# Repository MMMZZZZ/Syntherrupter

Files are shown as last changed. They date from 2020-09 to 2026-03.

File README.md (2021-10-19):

# Syntherrupter

Powerful MIDI interrupter with touchscreen for up to 6 tesla coils and 16 voices per coil. 

By Max Zuidberg. Credits [below](#credits).

## Index 

* [Features](#features)
* [Documentation and Getting Started](#documentation-and-getting-started)
* [Pictures](#pictures)
* [Demo Videos](#demo-videos)
* [PC MIDI Setup](#pc-midi-setup)
* [Credits](#credits)

## Features

* A unique and truly awesome name: Syntherrupter. ;D 
* **Easy to build**. Except for the optical transmitters the other parts are "ready to use" modules that can be connected without soldering or custom PCBs.
* **Over 10 voice polyphony** including effects like pitch bend, modulation and different "instruments". Yes, you can - within limits - change how your coil sounds.
* Control up to **6 independant tesla coils** with only one interrupter. And yes, each output can play different notes. Simply select which output should listen to which MIDI channel.
* Set and change hard limits for each coil. They will be stored even when powered off and assure that you don't fry your tesla coil no matter how crazy the MIDI file is.
* Advanced stereo features. Notes and MIDI channels can seamlessly change between multiple coils, creating **fascinating visual effects**.
* **Lightsabers**! An ESP8266, an IMU and a battery form a lightsaber that connects to Syntherrupter and allows "lightsaber-effects" to be played on your tesla coils! (credits: Netzpfuscher)
* Different users with different limits. This is useful if you want to rent the coil to someone else who does not know the coils (thermal?) limits as well as you do.
* **[Controllable via MIDI files](https://github.com/MMMZZZZ/Syfoh#readme)**. Any configuration can be embedded into your MIDI file. Just hit play and everything else happens automagically.
* Sounds boring, but for me it belongs to an interrupter as well: **Normal interrupter mode** where you can control the ontime, BPS and duty.
* **[Documentation/Wiki](/Documentation/Wiki#readme)**. This is not a joke; the wiki contains almost as much work as the software itself. It's not perfect but it covers pretty much everything from simple guides to technical documnetation.

## Documentation and Getting Started

Pretty much everything can be found in the [Wiki](/Documentation/Wiki#readme). For newcomers, there's a [Getting Started Guide](/Documentation/Wiki/Getting%20Started.md#readme). 

## Pictures

SimonNwardUKs version for 4 coils:
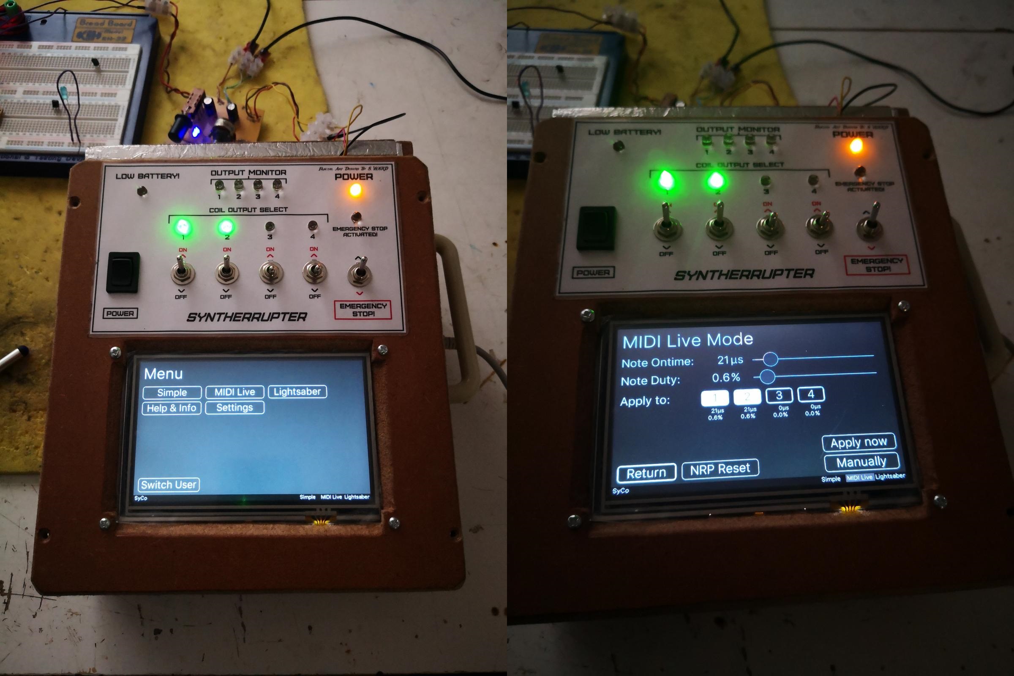
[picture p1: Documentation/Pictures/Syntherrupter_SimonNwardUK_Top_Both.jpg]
Syntherrupter Max Back


Internals of my single output version (with excessive optical receiver):
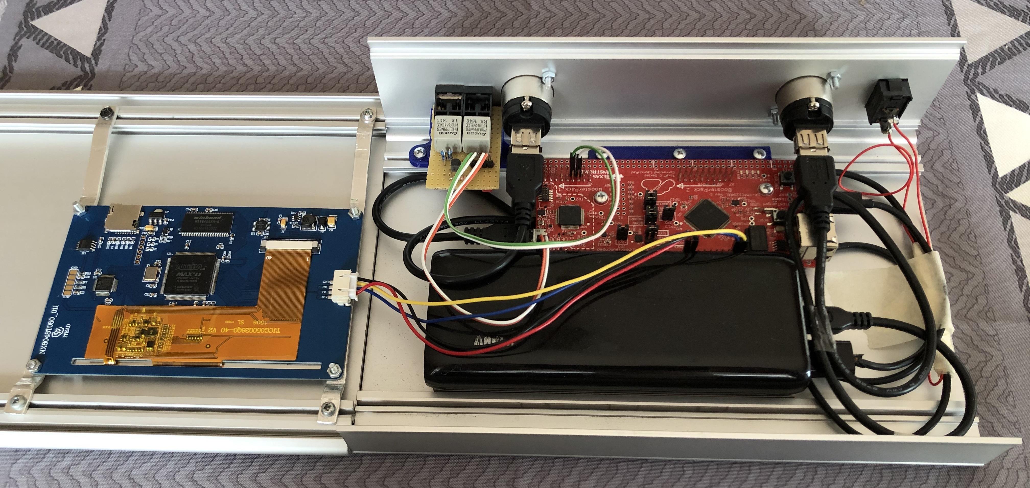
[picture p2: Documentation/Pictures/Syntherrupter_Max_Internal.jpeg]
Syntherrupter Max Inside


## Demo Videos

The following two videos demonstrate Syntherrupters capabilities but there are no arcs because I haven't had any opportunity to run my tesla coil. 

* [Queen - I Want It All](http://www.youtube.com/watch?v=H2ykCsD_b5g). A MIDI with ~6 voices, pitch bending, sometimes very fast notes, and other effects.

* [ACDC - Thunderstruck](http://www.youtube.com/watch?v=Tyts9u0le6A). This is a 6 channel demo of Syntherrupters stereo features with Thunderstruck. The only modification made to the MIDI file, were the commands that set up Syntherrupters stereo mode (documented [here](/Documentation/Wiki/Custom%20MIDI%20Commands.md)). The mapping of the notes to the coils (represented by LEDs) in done automatically.

    *"I must say that the Omni-mode is what I have dreamt about for years, I am really looking forward to use that feature (and not so much that I now have to build 6 identical coils)"* ([from Mads Barnkob](https://highvoltageforum.net/index.php?topic=1020.msg8430#msg8430))

* [ABBA - Gimme! Gimme! Gimme!](https://www.youtube.com/watch?v=6n-RvNdsbxE). Perfect demo of the [staccato envelope](/Documentation/Wiki/Envelopes.md#readme). Note how the low notes are not "on, off" but more like a quick fade in and fade out with slight reverb. That's the envelope. Compare it with the videos below, which do not use this feature

Then there are a few videos from other people that build their own Syntherrupter:
* [Video (performed by Georgios)](https://www.youtube.com/watch?v=1vgiw4VHPKQ). Fast MIDI with 2 tesla coils and up to 4 notes per coil
* [O-Zone - Dragostea Din Tei (performed by futurist)](https://www.youtube.com/watch?v=86U6sI6FZ6c). 1 Coil, two notes, nonetheless a good MIDI.
* [Fonsi - Despacito and much more (performed by futurist)](https://www.youtube.com/playlist?list=PLlkH_ZpBGiexB1ahBjtajvHqJAfMIxrB1). Playlist with a lot of popular songs. Usually only 2 notes at most, played by 2 coils. 

## PC MIDI Setup

To open and play MIDI files I use the free software [SynthFont 1](http://www.synthfont.com/). You can select a different output for each track which we can use to send some tracks to the interrupter. You might want to change the instrument of these tracks to use Syntherrupters [envelopes](/Documentation/Wiki/Envelopes.md#readme). For good sound quality download the [SGMv2.01-Sal-Guitar-Bass-v1.3](https://sites.google.com/site/soundfonts4u) soundfont).

While SynthFont allows you to send MIDI data directly to a serial port and thus to Syntherrupter, I do recommend another solution. In my experience it is easier to use, more reliable and works with any MIDI software you like. All you need are two little tools that are very easy to use: [Hairless MIDI<->Serial](https://projectgus.github.io/hairless-midiserial/) and [loopMIDI](https://www.tobias-erichsen.de/software/loopmidi.html). When you start loopMIDI it creates a virtual MIDI device that you can select in any MIDI software as output (or input btw). And hairless MIDI<->Serial makes the bridge between this virtual MIDI device and the serial COM port.
This sounds complicated but since both programs remember all settings, you only have to start them - no other click needed. The setup has proven its reliability and usability many times and for many hours. 

## Credits

[Netzpfuscher and his awesome UD3](https://highvoltageforum.net/index.php?topic=188.0). Thank you for the initial help with polyphony and the awesome lightsaber idea.

[TMaxElectronics](https://tmax-electronics.de/easteregg/). Many great discussions about MIDI, Interrupters, C/C++ worst practices, and much more. And for developing a competing interrupter - keeps the development going. 

[highvoltageforum](https://highvoltageforum.net). Without those people sharing their ideas and knowledge, Syntherrupter would never be where it is now.

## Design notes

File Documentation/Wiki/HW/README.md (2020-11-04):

# Hardware Reference

[Back to the wiki main page](/Documentation/Wiki/README.md#readme)

This page and its subpages document every aspect of Syntherrupters hardware.

## Content

* [Optical Outputs](Optical%20Outputs.md#readme)
* [MIDI Input Jack](MIDI%20Input.md#readme)
* [Lightsaber Receiver](Lightsaber%20Receiver.md#readme)

All the schematics and pinouts you see in these pages come from the *[Wiring and Schematics](/Documentation/Wiring%20and%20Schematics)* folder. It contains not only the pictures but also the source files (f.ex. Fritzing files).

All of the Datasheets and manuals can be found in the  *[Datasheets](/Documentation/Datasheets)* folder.

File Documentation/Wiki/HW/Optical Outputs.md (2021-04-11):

# Optical Outputs

[Back to the hardware documentation overview](README.md#readme)

The connection between interrupter and tesla coil driver is usually made with fibre optics. This page explains how to add optic transmitters to Syntherrupter. 

Syntherrupter can generate up to 6 independant interrupter signals (for up to 6 independent tesla coils). You're completely free in the choice of how many outputs you want to have on your Syntherrupter; 1, 2, 3, 4, 5 or 6 are possible. In any case you'll need one transmitter per output. 

## Output Pins and Limits

The 6 output signals are available on the following Tiva pins:

* PD0: Output 1
* PD2: Output 2
* PM0: Output 3
* PM2: Output 4
* PM4: Output 5
* PM6: Output 6

All output pins are 3.3V active high and capable of 12mA max. Depending on your transmitter this is not enough to drive its LED. Please check the datasheet for the recommended current. In case your transmitter needs more current (the HFBR-14E4Z f.ex. needs 60mA) you'll need some additional circuitry. Nothing complicated, a standard NPN transistors and 2 resistors do the job. As always, details in the wiring and schematic folder linked at the top.

## Schematic

The following Schematic of a "complete" Syntherrupter shows how to connect the NPN transistors and what resistor values are needed. **Remember** to adjust the LED resistor for your current! The resistor value can easily be calculated using the following formula: `R_LED = (V_CC - V_CE - V_f) / I_f = (4.4 - V_f) / I_f`

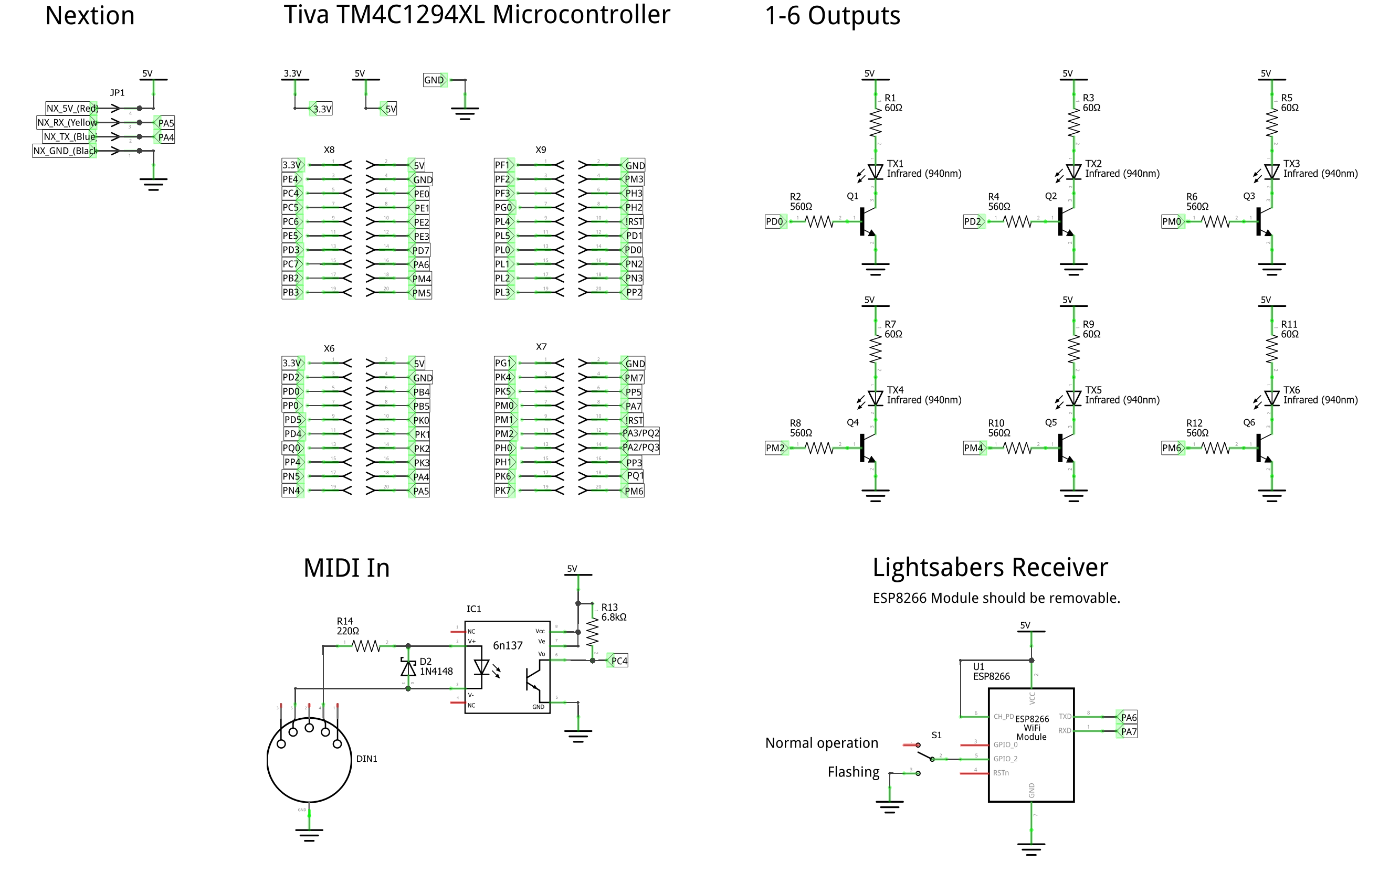
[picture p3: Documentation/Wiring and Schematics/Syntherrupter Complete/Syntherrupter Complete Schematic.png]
Complete Schematic


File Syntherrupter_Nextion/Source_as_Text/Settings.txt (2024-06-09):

Page Settings
    Attributes
        ID               : 0
        Scope            : local
        Send Component ID: disabled
        Locked           : no
    
    Events
        Preinitialize Event
            // Prevent page refreshs until postinit
            ref_stop
            //
            // Load colors
            click fLoadColors,1
            click fLoadModes,1
            //
            // Display username
            if(User_Settings.userNum.val==0)
            {
                tUser.txt=" "+User_Settings.u0Name.txt
            }else if(User_Settings.userNum.val==1)
            {
                tUser.txt=" "+User_Settings.u1Name.txt
            }else if(User_Settings.userNum.val==2)
            {
                tUser.txt=" "+User_Settings.u2Name.txt
            }
            //
            vis fLoadModes,0
            vis fLoadColors,0
            //
            // Properly hide the help stuff.
            vis hHelp,0
            vis tHelp,0
            //
            tSave.bco=Settings.backSelectCol2.val
            vis tSave,Settings.unsaved.val
            // Not all users have the same rights
            if(User_Settings.userNum.val!=2)
            {
                vis bCoilSettings,0
                vis bNXTUpdate,0
                vis bESPUpdate,0
                vis bReset,0
            }
            //
            // Enable page refreshs again
            ref_star
        
        Postinitialize Event
            // Accept data on this page
            // Send a Syntherrupter Sysex command
            // Package format:
            // F0 00 DMID DMID VERSION DEVICE PN_LSB PN_MSB TG_LSB TG_MSB VAL_LSB VAL VAL VAL VAL_MSB F7
            // DMID DMID = 26 05
            // VERSION = 01
            // DEVICE = 7f (wildcard)
            // PN, TG, VAL: see syntherrupter sysex documentation
            //
            // SYSEX_START DMID VERSION DEVICE
            printh f0 00 26 05 01 7f
            // PN_LSB PN_MSB
            printh 26 02 // GUI Update Mode
            // TG_LSB TG_MSB
            printh 00 00 // Reserved
            // VAL (4 bytes to be packed into 5 groups of 7 bit)
            // 2: Keep UI updated
            printh 02 00 00 00 00
            // SYSEX_END
            printh f7
        
        Touch Press Event
            if(Other_Settings.backOff.val!=0)
            {
                // Default "stop" action.
                // Set ontime and duty to 0 for all modes. See fSysex for details
                // Disable all modes as well.
                printh f0 00 26 05 01 7f 20 00 00 7f 00 00 00 00 00 f7
                printh f0 00 26 05 01 7f 21 00 00 7f 00 00 00 00 00 f7
                printh f0 00 26 05 01 7f 22 00 00 7f 00 00 00 00 00 f7
                // Set all ontime and duty settings of all pages to 0.
                // First come the global variables then the local variables.
                Simple.ontime.val=0
                Simple.duty.val=0
                Simple.set1.val=Simple.set1.val&0x0000ffff
                Simple.set2.val=Simple.set2.val&0x0000ffff
                Simple.set3.val=Simple.set3.val&0x0000ffff
                Simple.set4.val=Simple.set4.val&0x0000ffff
                Simple.set5.val=Simple.set5.val&0x0000ffff
                Simple.set6.val=Simple.set6.val&0x0000ffff
                MIDI_Live.ontime.val=0
                MIDI_Live.duty.val=0
                MIDI_Live.set1.val=0
                MIDI_Live.set2.val=0
                MIDI_Live.set3.val=0
                MIDI_Live.set4.val=0
                MIDI_Live.set5.val=0
                MIDI_Live.set6.val=0
                Lightsaber.ontime.val=0
                Lightsaber.ontimes12.val=0
                Lightsaber.ontimes34.val=0
                Lightsaber.ontimes56.val=0
            }
        
        Page Exit Event
            // Leaving this page, the UI might not accept data anymore (any page that still accepts it,
            // will enable it again).
            // Send a Syntherrupter Sysex command
            // Package format:
            // F0 00 DMID DMID VERSION DEVICE PN_LSB PN_MSB TG_LSB TG_MSB VAL_LSB VAL VAL VAL VAL_MSB F7
            // DMID DMID = 26 05
            // VERSION = 01
            // DEVICE = 7f (wildcard)
            // PN, TG, VAL: see syntherrupter sysex documentation
            //
            // SYSEX_START DMID VERSION DEVICE
            printh f0 00 26 05 01 7f
            // PN_LSB PN_MSB
            printh 26 02 // GUI Update Mode
            // TG_LSB TG_MSB
            printh 00 00 // Reserved
            // VAL (4 bytes to be packed into 5 groups of 7 bit)
            // 0: No UI updates
            printh 00 00 00 00 00
            // SYSEX_END
            printh f7
        
Variable (int32) currentHelp
    Attributes
        ID   : 1
        Scope: local
        Value: 4294967295
    
Variable (int32) backCol
    Attributes
        ID   : 2
        Scope: global
        Value: 8484
    
Variable (int32) backCol2
    Attributes
        ID   : 3
        Scope: global
        Value: 2145
    
Variable (int32) frontCol
    Attributes
        ID   : 4
        Scope: global
        Value: 40476
    
Variable (int32) frontCol2
    Attributes
        ID   : 5
        Scope: global
        Value: 40476
    
Variable (int32) backSelectCol2
    Attributes
        ID   : 6
        Scope: global
        Value: 16904
    
Variable (int32) backCol2Deflt
    Attributes
        ID   : 7
        Scope: global
        Value: 4589
    
Variable (int32) colorMode
    Attributes
        ID   : 8
        Scope: global
        Value: 1
    
Variable (int32) picCount
    Attributes
        ID   : 9
        Scope: global
        Value: 43
    
Variable (int32) activeModes
    Attributes
        ID   : 20
        Scope: global
        Value: 0
    
Variable (int32) applyingMode
    Attributes
        ID   : 28
        Scope: global
        Value: 1
    
Variable (int32) firstHelp
    Attributes
        ID   : 31
        Scope: global
        Value: 1
    
Variable (int32) unsaved
    Attributes
        ID   : 32
        Scope: global
        Value: 0
    
Variable (int32) CM0backCol
    Attributes
        ID   : 35
        Scope: global
        Value: 65535
    
Variable (int32) CM0backCol2
    Attributes
        ID   : 36
        Scope: global
        Value: 4589
    
Variable (int32) CM0frontCol
    Attributes
        ID   : 37
        Scope: global
        Value: 6900
    
Variable (int32) CM0frontCol2
    Attributes
        ID   : 38
        Scope: global
        Value: 65535
    
Variable (int32) CM0backSelCol2
    Attributes
        ID   : 39
        Scope: global
        Value: 6900
    
Variable (int32) CM1backCol
    Attributes
        ID   : 40
        Scope: global
        Value: 8484
    
Variable (int32) CM1backCol2
    Attributes
        ID   : 41
        Scope: global
        Value: 2145
    
Variable (int32) CM1frontCol
    Attributes
        ID   : 42
        Scope: global
        Value: 40476
    
Variable (int32) CM1frontCol2
    Attributes
        ID   : 43
        Scope: global
        Value: 40476
    
Variable (int32) CM1backSelCol2
    Attributes
        ID   : 44
        Scope: global
        Value: 16904
    
Text tUser
    Attributes
        ID                 : 10
        Scope              : local
        Send Component ID  : disabled
        Associated Keyboard: none
        Text               :  Guest
        Max. Text Size     : 32
    
    Events
        Touch Press Event
            // Make this object "transparent" for clicks and click background.
            click 0,1
        
Text tMSI
    Attributes
        ID                 : 11
        Scope              : local
        Send Component ID  : disabled
        Associated Keyboard: none
        Text               : Simple
        Max. Text Size     : 16
    
    Events
        Touch Press Event
            // Make this object "transparent" for clicks and click background.
            click 0,1
        
Text tMML
    Attributes
        ID                 : 12
        Scope              : local
        Send Component ID  : disabled
        Associated Keyboard: none
        Text               : MIDI Live
        Max. Text Size     : 16
    
    Events
        Touch Press Event
            // Make this object "transparent" for clicks and click background.
            click 0,1
        
Text tMLS
    Attributes
        ID                 : 13
        Scope              : local
        Send Component ID  : disabled
        Associated Keyboard: none
        Text               : Lightsaber
        Max. Text Size     : 16
    
    Events
        Touch Press Event
            // Make this object "transparent" for clicks and click background.
            click 0,1
        
Text tSave
    Attributes
        ID                 : 14
        Scope              : local
        Send Component ID  : disabled
        Associated Keyboard: none
        Text               : Unsaved Settings!
        Max. Text Size     : 40
    
    Events
        Touch Press Event
            // Make this object "transparent" for clicks and click background.
            click 0,1
        
Text tHelp
    Attributes
        ID                 : 15
        Scope              : local
        Send Component ID  : disabled
        Associated Keyboard: none
        Text               : 
        Max. Text Size     : 650
    
    Events
        Touch Press Event
            // This object is only visible in help mode. No need to be "transparent" to clicks in normal operation.
            click bReturn,0
        
Text tTitle
    Attributes
        ID                 : 17
        Scope              : local
        Send Component ID  : disabled
        Associated Keyboard: none
        Text               : Settings
        Max. Text Size     : 22
    
Button bDiscard
    Attributes
        ID               : 16
        Scope            : local
        Send Component ID: disabled
        State            : unpressed
        Text             : Discard
        Max. Text Size   : 20
    
    Events
        Touch Release Event
            // Force EEPROM Reload
            // Send a Syntherrupter Sysex command
            // Package format:
            // F0 00 DMID DMID VERSION DEVICE PN_LSB PN_MSB TG_LSB TG_MSB VAL_LSB VAL VAL VAL VAL_MSB F7
            // DMID DMID = 26 05
            // VERSION = 01
            // DEVICE = 7f (wildcard)
            // PN, TG, VAL: see syntherrupter sysex documentation
            //
            // EEPROM Reload
            // SYSEX_START DMID VERSION DEVICE
            printh f0 00 26 05 01 7f
            // PN_LSB PN_MSB
            printh 00 02 // EEPROM Update
            // TG_LSB TG_MSB
            printh 00 00 // Reserved
            // VAL (4 bytes to be packed into 5 groups of 7 bit)
            // Update Mode. 1: Reload all settings from EEPROM
            printh 03 00 00 00 00
            // SYSEX_END
            printh f7
            //
            unsaved.val=0
            vis tSave,0
        
Button bReturn
    Attributes
        ID               : 18
        Scope            : local
        Send Component ID: disabled
        State            : unpressed
        Text             : â†
        Max. Text Size   : 3
    
    Events
        Touch Release Event
            page Menu
        
Button bCoilSettings
    Attributes
        ID               : 21
        Scope            : local
        Send Component ID: disabled
        State            : unpressed
        Text             : Coil Limits
        Max. Text Size   : 20
    
    Events
        Touch Release Event
            TC_Settings.origin.val=dp
            page TC_Settings
        
Button bSave
    Attributes
        ID               : 22
        Scope            : local
        Send Component ID: disabled
        State            : unpressed
        Text             : Save
        Max. Text Size   : 10
    
    Events
        Touch Release Event
            // Force EEPROM update
            // Send a Syntherrupter Sysex command
            // Package format:
            // F0 00 DMID DMID VERSION DEVICE PN_LSB PN_MSB TG_LSB TG_MSB VAL_LSB VAL VAL VAL VAL_MSB F7
            // DMID DMID = 26 05
            // VERSION = 01
            // DEVICE = 7f (wildcard)
            // PN, TG, VAL: see syntherrupter sysex documentation
            //
            // EEPROM Update
            // SYSEX_START DMID VERSION DEVICE
            printh f0 00 26 05 01 7f
            // PN_LSB PN_MSB
            printh 00 02 // EEPROM Update
            // TG_LSB TG_MSB
            printh 00 00 // Reserved
            // VAL (4 bytes to be packed into 5 groups of 7 bit)
            // Update Mode. 1: Forced update.
            printh 01 00 00 00 00
            // SYSEX_END
            printh f7
            //
            unsaved.val=0
            vis tSave,0
        
Button bNXTUpdate
    Attributes
        ID               : 23
        Scope            : local
        Send Component ID: disabled
        State            : unpressed
        Text             : Nextion<->USB
        Max. Text Size   : 20
    
    Events
        Touch Release Event
            page USB_NXT_Pass
        
Button bGeneral
    Attributes
        ID               : 24
        Scope            : local
        Send Component ID: disabled
        State            : unpressed
        Text             : General
        Max. Text Size   : 20
    
    Events
        Touch Release Event
            page Other_Settings
        
Button bUsers
    Attributes
        ID               : 25
        Scope            : local
        Send Component ID: disabled
        State            : unpressed
        Text             : Users
        Max. Text Size   : 20
    
    Events
        Touch Release Event
            User_Settings.origin.val=dp
            page User_Settings
        
Button bEnvelope
    Attributes
        ID               : 26
        Scope            : local
        Send Component ID: disabled
        State            : unpressed
        Text             : Envelopes
        Max. Text Size   : 20
    
    Events
        Touch Release Event
            Env_Settings.origin.val=dp
            page Env_Settings
        
Button bESPUpdate
    Attributes
        ID               : 27
        Scope            : local
        Send Component ID: disabled
        State            : unpressed
        Text             : ESP<->USB
        Max. Text Size   : 20
    
    Events
        Touch Release Event
            page USB_ESP_Pass
        
Button bReset
    Attributes
        ID               : 30
        Scope            : local
        Send Component ID: disabled
        State            : unpressed
        Text             : Reset ÂµC
        Max. Text Size   : 20
    
    Events
        Touch Release Event
            // Reset Tiva
            // Send a Syntherrupter Sysex command
            // Package format:
            // F0 00 DMID DMID VERSION DEVICE PN_LSB PN_MSB TG_LSB TG_MSB VAL_LSB VAL VAL VAL VAL_MSB F7
            // DMID DMID = 26 05
            // VERSION = 01
            // DEVICE = 7f (wildcard)
            // PN, TG, VAL: see syntherrupter sysex documentation
            //
            // Reset
            // SYSEX_START DMID VERSION DEVICE
            printh f0 00 26 05 01 7f
            // PN_LSB PN_MSB
            printh 02 02 // Reset
            // TG_LSB TG_MSB
            printh 00 00 // Reserved
            // VAL (4 bytes to be packed into 5 groups of 7 bit)
            // 41153700: key for reset
            sys1=41153700
            sys2=sys1
            sys2&=0x7f
            prints sys2,1
            sys1>>=7
            sys2=sys1&0x7f
            prints sys2,1
            sys1>>=7
            sys2=sys1&0x7f
            prints sys2,1
            sys1>>=7
            sys2=sys1&0x7f
            prints sys2,1
            sys1>>=7
            sys2=sys1&0x7f
            prints sys2,1
            // SYSEX_END
            printh f7
            //
            // Not really necessary but doesn't hurt either.
            page Menu
            //
            unsaved.val=0
            vis tSave,0
        
Dual-state Button btHelp
    Attributes
        ID               : 19
        Scope            : local
        Send Component ID: disabled
        State            : unpressed
        Text             : ?
        Max. Text Size   : 1
    
    Events
        Touch Release Event
            if(btHelp.val==0)
            {
                // In case something was displayed, get rid of it
                bReturn.val=1
                click hHelp,0
                // disable help overlay
                vis hHelp,0
            }else
            {
                vis hHelp,1
            }
        
Hotspot fLoadModes
    Attributes
        ID               : 29
        Scope            : local
        Send Component ID: disabled
    
    Events
        Touch Press Event
            // Load active modes
            sys0=Settings.activeModes.val&4
            if(sys0!=0)
            {
                // Lightsaber Mode is active
                tMLS.bco=Settings.backSelectCol2.val
            }
            //
            // Display all active modes
            sys0=Settings.activeModes.val&1
            if(sys0!=0)
            {
                // Simple Mode is active
                tMSI.bco=Settings.backSelectCol2.val
            }
            sys0=Settings.activeModes.val&2
            if(sys0!=0)
            {
                // MIDI Live Mode is active
                tMML.bco=Settings.backSelectCol2.val
            }
        
Hotspot fLoadColors
    Attributes
        ID               : 33
        Scope            : local
        Send Component ID: disabled
    
    Events
        Touch Press Event
            // Changes all page components according to the current color set.
            // Note: This component has to be the last component of the page.
            //
            // sys0: component id
            // sys1: component type
            // sys2: picture id offset for current color mode
            sys2=Settings.colorMode.val*Settings.picCount.val
            for(sys0=0;sys0<fLoadColors.id;sys0++)
            {
                // More convenient for typing
                sys1=b[sys0].type
                if(sys1==121)
                {
                    // Types that have bco
                    // page
                    if(b[sys0].bco==Settings.backCol2Deflt.val)
                    {
                        b[sys0].bco=Settings.backCol2.val
                    }else
                    {
                        b[sys0].bco=Settings.backCol.val
                    }
                }else if(sys1==54||sys1==59||sys1==116||sys1==55)
                {
                    // Types that have bco, pco, and sta:
                    // number, float, text, scroll text
                    if(b[sys0].sta==1)
                    {
                        if(b[sys0].bco==Settings.backCol2Deflt.val)
                        {
                            b[sys0].bco=Settings.backCol2.val
                            b[sys0].pco=Settings.frontCol2.val
                        }else
                        {
                            b[sys0].bco=Settings.backCol.val
                            b[sys0].pco=Settings.frontCol.val
                        }
                    }
                }else if(sys1==98||sys1==53)
                {
                    // Types that have pco, pic, pco2, pic2, sta:
                    // button, dual-state button
                    if(b[sys0].sta==2)
                    {
                        b[sys0].pco=Settings.frontCol.val
                        b[sys0].pco2=Settings.backCol.val
                        b[sys0].pic=b[sys0].pic%Settings.picCount.val
                        b[sys0].pic+=sys2
                        b[sys0].pic2=b[sys0].pic+1
                    }
                }else if(sys1==58)
                {
                    // Types that have bco, pco
                    // QR Code
                    b[sys0].bco=Settings.backCol.val
                    b[sys0].pco=Settings.frontCol.val
                }else if(sys1==1)
                {
                    // Types that have pic, pic1, pic2:
                    // slider
                    b[sys0].pic=b[sys0].pic%Settings.picCount.val
                    b[sys0].pic+=sys2
                    b[sys0].pic1=b[sys0].pic
                    b[sys0].pic2=b[sys0].pic2%Settings.picCount.val
                    b[sys0].pic2+=sys2
                }
            }
        
Hotspot hHelp
    Attributes
        ID               : 34
        Scope            : local
        Send Component ID: disabled
    
    Events
        Touch Press Event
            // Determine component/feature that would have been touched.
            sys1=0
            for(sys0=fLoadColors.id;sys0>=0;sys0--)
            {
                // Ignore hotspots, touchcaps, variables
                if(b[sys0].type!=5&&b[sys0].type!=51&&b[sys0].type!=52&&b[sys0].type!=109)
                {
                    x0=b[sys0].x
                    y0=b[sys0].y
                    x1=b[sys0].w
                    y1=b[sys0].h
                    x1+=x0
                    y1+=y0
                    if(tch0>=x0&&tch0<x1&&tch1>=y0&&tch1<y1)
                    {
                        sys1=sys0
                        // abort loop
                        sys0=-1
                    }
                }
            }
            if(currentHelp.val>=0&&sys1==bReturn.id)
            {
                // Return button has been pressed while help is being displayed. This means
                // hide the help text again (see touch release event)
                bReturn.val=1
            }else if(sys1==btHelp.id)
            {
                // Question mark button has been pressed. Disable help mode (see touch release event).
                btHelp.val=0
            }else if(currentHelp.val>=0)
            {
                // Help is being displayed and something else has been pressed.
                // Act as if the page background had been pressed.
                // Note: this can make other UI elements to "pop up", therefore bring the text back on top
                // TODO: Prevent flickering!
                click 0,1
                doevents
                ref tHelp
            }else
            {
                // Show help according to what has been touched.
                // Assume that some new help will be displayed
                sys0=1
                tHelp.txt=""
                if(Settings.firstHelp.val!=0)
                {
                    Settings.firstHelp.val=0
                    tHelp.txt+="Help Mode Enabled \r\r"
                    tHelp.txt+="You've enabled the on-screen help by pressing the question mark at the top right \r"
                    tHelp.txt+="corner. As long as it's active, you can press any part of the UI and get a description \r"
                    tHelp.txt+="of what that button/slider/... does. \r"
                    tHelp.txt+="Press the X button at the top left to get help on another part of the UI. \r"
                    tHelp.txt+="Press the question mark at the top right to leave help mode and resume normal\r"
                    tHelp.txt+="operation. \r"
                    tHelp.txt+="Press any other part of the screen, including this description, to disable all outputs. \r"
                    tHelp.txt+="For more information, check the help on the page background.\r"
                    tHelp.txt+=" \r"
                    tHelp.txt+="This tip won't reappear until you reset or power cycle Syntherrupter. \r"
                }else if(sys1==tTitle.id||sys1==bReturn.id) // In this case bReturn overlays the title box.
                {
                    tHelp.txt+="Settings\r\r"
                    tHelp.txt+="From here you can access all of Syntherrupters settings as well as the serial bridge modes. \r"
                    tHelp.txt+="All settings are applied immediately but only stored permanently once you hit the 'Save' \r"
                    tHelp.txt+="button below. \r"
                    tHelp.txt+="\r"
                    tHelp.txt+="If you want to leave help mode, press the question mark at the top left. \r"
                }else if(sys1==tUser.id)
                {
                    tHelp.txt+="Current User \r\r"
                    tHelp.txt+="The name of the currently active user. This determines the range within which you \r"
                    tHelp.txt+="can operate Syntherrupter. Go to the main menu to change the current user. \r"
                }else if(sys1==tMSI.id||sys1==tMML.id||sys1==tMLS.id)
                {
                    tHelp.txt+="Active Modes \r\r"
                    tHelp.txt+="Modes can stay active even if you leave the corresponding page. Active modes are \r"
                    tHelp.txt+="highlighted at the bottom right. \r"
                }else if(sys1==0||sys1==tHelp.id)
                {
                    tHelp.txt+="Page background \r\r"
                    tHelp.txt+="The page background, textboxes and non-interactive elements in general shut down \r"
                    tHelp.txt+="all outputs if you press them. This allows you to quickly stop all outputs and all \r"
                    tHelp.txt+="modes if something goes wrong. \r"
                    tHelp.txt+="Note however, that unplugging power is the only actually safe way to ensure a complete \r"
                    tHelp.txt+="shutdown! \r"
                    tHelp.txt+="This feature can be temporarily disabled in the general settings. After a reset or \r"
                    tHelp.txt+="power-cycle it will be enabled again.\r"
                }else if(sys1==bReturn.id)
                {
                    tHelp.txt+="Return Button\r\r"
                    tHelp.txt+="Return to the main menu. \r"
                    tHelp.txt+="\r"
                    tHelp.txt+="If you want to leave help mode, press the question mark at the top left. \r"
                }else if(sys1==bGeneral.id)
                {
                    tHelp.txt+="General Settings\r\r"
                    tHelp.txt+="Mostly settings related to the UI, f.ex. screen brightness and dark mode. \r"
                }else if(sys1==bUsers.id)
                {
                    tHelp.txt+="User Settings and Limits\r\r"
                    tHelp.txt+="Set user names and passwords as well as the limits within which they may operate. \r"
                }else if(sys1==bEnvelope.id)
                {
                    tHelp.txt+="Envelope Editor\r\r"
                    tHelp.txt+="Envelopes can significantly improve the sound of your tesla coils. I'd suggest you \r"
                    tHelp.txt+="try it by setting the instrument of your MIDI track(s) to  '10: Glockenspiel'. \r"
                    tHelp.txt+="If you want to modify the characteristics of the envelope you can do it here in the \r"
                    tHelp.txt+="envelope editor. You should check the documentation first though. \r"
                }else if(sys1==bCoilSettings.id)
                {
                    tHelp.txt+="Coil Limits\r\r"
                    tHelp.txt+="The coil limits determine the safe operating range of each one of your tesla coils.\r"
                    tHelp.txt+="Syntherrupter will not exceed these values no matter your settings here or elsewhere. \r"
                    tHelp.txt+="Simple Mode is one of the easier ways to test and tune your limits. \r"
                }else if(sys1==bNXTUpdate.id)
                {
                    tHelp.txt+="Nextion <-> USB Serial Passthrough\r\r"
                    tHelp.txt+="Entering this page virtually connects the Nextion serial pins to the USB serial pins. \r"
                    tHelp.txt+="This mode works for any baudrate up to about 512kbaud/s. \r"
                    tHelp.txt+="All other functions of Syntherrupter will stop working. Exiting this mode requires a reset \r"
                    tHelp.txt+="or power cycle. \r"
                }else if(sys1==bESPUpdate.id)
                {
                    tHelp.txt+="ESP <-> USB Serial Passthrough\r\r"
                    tHelp.txt+="Entering this page virtually connects the Nextion serial pins to the USB serial pins. \r"
                    tHelp.txt+="This mode works for any baudrate up to about 512kbaud/s. \r"
                    tHelp.txt+="All other functions of Syntherrupter will stop working. Exiting this mode requires a reset \r"
                    tHelp.txt+="or power cycle. \r"
                }else if(sys1==bSave.id)
                {
                    tHelp.txt+="Save and Return\r\r"
                    tHelp.txt+="Save settings permanently and return to the main menu. \r"
                }else if(sys1==bDiscard.id)
                {
                    tHelp.txt+="Discard Settings\r\r"
                    tHelp.txt+="Discard all settings by reloading them from EEPROM. \r"
                }else if(sys1==bReset.id)
                {
                    tHelp.txt+="Reset\r\r"
                    tHelp.txt+="Reset Syntherrupter, discarding all settings. \r"
                }else
                {
                    // Nope, no new help text to be displayed
                    sys0=0
                }
                if(sys0!=0)
                {
                    currentHelp.val=sys1
                    vis tHelp,1
                    if(bReturn.txt!="âœ•")
                    {
                        bReturn.txt="âœ•"
                    }
                }
            }
        
        Touch Release Event
            // Check if help text is being displayed and shall be hidden again
            if(bReturn.val==1)
            {
                bReturn.val=0
                if(bReturn.txt!="â†")
                {
                    bReturn.txt="â†"
                }
                vis tHelp,0
                currentHelp.val=-1
            }else if(sys1==btHelp.id)
            {
                click btHelp,0
            }

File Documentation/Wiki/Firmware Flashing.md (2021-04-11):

# Syntherrupter Firmware Flashing

[Back to the wiki main page](README.md#readme)

This page covers how to flash a (new) firmware on your Syntherrupter.

## Index
* [Index](#index)
* [Note about beta versions](#note-about-beta-versions)
* [Flashing Order and Recovery](#flashing-order-and-recovery)
* [Tiva Flashing](#tiva-flashing)
* [Nextion Flashing over USB/Serial](#nextion-flashing-over-usbserial)
* [Nextion Flashing with a microSD card](#nextion-flashing-with-a-microsd-card)

## Note about beta versions
Beta versions usually include new features that do not touch the core of Syntherrupter. This means it's *highly unlikely* that the update breaks the cores safety features, namely the specified maximum ontime, minimum offtime and maximum duty. However, you should not expect any part of the GUI or any of Syntherrupters modes to be free of bugs. 

## Flashing Order and Recovery

*This only concerns firmware updates and assumes you already have a working setup.* 

Firmware updates always consist of a new Nextion and a new Tiva firmware. Unless the release notes say something different, you should update the Nextion firmware first. The reason is that you can always flash the Tiva microcontroller but in order to flash Nextion you need a working Syntherrupter that allows you to enter [Nextion<->USB Passthrough Mode](UI/Nextion-USB.md#readme).

Usually if a Nextion firmware update goes wrong, the Tiva microcontroller will automatically enter [Nextion<->USB Passthrough Mode](UI/Nextion-USB.md#readme), allowing you to reflash the firmware. However, if you flashed f.ex. the wrong version it can happen that this check is successful but Syntherrupter is still unusable. In this case you can either [update Nextion using a microSD card](#nextion-flashing-with-a-microsd-card), or disconnect the Nextion screen when powering up Syntherrupter. Wait 5 seconds, and reconnect. This makes sure that the Tiva firmware entered Nextion<->USB passthrough mode and you can [flash the Nextion firmware over USB](#nextion-flashing-over-usbserial) again. 

## Tiva Flashing

### Requirements
* Windows. The tools used are not available for other operating systems.
* [Latest Syntherrupter release](https://github.com/MMMZZZZ/Syntherrupter/releases/)
* [Drivers](/Utilities%20and%20Drivers/Tiva%20USB%20Drivers%20(Stellaris%20ICDI%20Drivers).zip?raw=true)
* [LM Flash Programmer](/Utilities%20and%20Drivers/LMFlashProgrammer_1613.msi?raw=true)

### Steps for Driver Installation
* Extract the *stellaris_icdi_drivers* folder from the drivers zip file.
* Connect Tiva LaunchPad to the PC via its DEBUG USB port. 
* Open the Device Manager. One or more unknown "ICDI" devices will be listed. If not, the drivers are already installed and you can skip the remaining steps.
* Right click on one of them
	* Choose update the drivers,
	* Search on the PC, 
	* Select the unzipped "stellaris_icdi_drivers". 
	* Repeat for all other unknown "ICDI" devices.

### Steps for Flashing
* Extract the Tiva firmware from the Syntherrupter release zip file. Based on the number of optic transmitters you have, select the right version. The firmware file (for X transmitters) is called "Syntherrupter_Tiva_X_Coils.bin".
* Install and open LM Flash Programmer. 
* On the tab *Configuration*, select *TM4C1294XL LaunchPad* from the *Quick Set* drop down list. 
* Switch to the tab "Program" and select the extracted .bin file.
* Select the following options: 
	* *Erase Entire Flash*
	* *Verify After Program*
	* *Reset MCU After Program*
* Click on *Program* to flash the microcontroller.

## Nextion Flashing over USB/Serial
You can upload a firmware to the Nextion screen using its serial connection. This is very convenient because you don't have to access the microSD card slot on the screen itself. 

Note: While the Nextion screen is configured to communicate at 115200baud/s, the Nextion upload protocol allows to switch to a different baud rate during the firmware upload. The highest possible baud rate is 512000baud/s. This speeds up the upload considerably, "only" taking about 1 minute.

### Requirements
* Windows. The tools used are not available for other operating systems.
* [Tiva Firmware](#tiva-flashing) up and running. 
* [Latest Syntherrupter release](https://github.com/MMMZZZZ/Syntherrupter/releases/)
* [TFTFileDownload](/Utilities%20and%20Drivers/TFTFileDownload.exe?raw=true)

### Steps
* Check the exact model number of your touch screen. 
* Extract the Nextion firmware for your model number from the Syntherrupter release zip file. The firmware file is called "Syntherrupter_Nextion_MODEL.tft". 
* Connect Syntherrupter to your computer and choose *Nextion<->USB* in Syntherrupters *Settings* menu. If your Nextion firmware is not working, the Tiva Firmware will automatically enter this mode after 3 seconds. 
* Open the TFTFileDownload tool and select the COM port. Baud rate should be 512000baud/s. In case you get timeout or other errors, try a lower baud rate. If even at 115200baud/s you can't upload the firmware, there's something wrong.
* Click on the *Down* button to start flashing. 
* Once the upload is done, the screen will reset and stay black until you power cycle Syntherrupter. 

## Nextion Flashing with a microSD card
In case the serial upload does not work or is too slow for you, you can try uploading the firmware using a microSD card. This update method is also useful if you have no access to a Windows PC. 

### Requirements
* [Latest Syntherrupter release](https://github.com/MMMZZZZ/Syntherrupter/releases/)
* microSD card. Note: some microSD cards do not work with the Nextion screen. I cannot tell you if your card will work or not. 

### Steps
* Make sure the microSD card is formatted as FAT32 and empty.
* Check the exact model number of your touch screen. 
* Copy the Nextion firmware for your model number from the Syntherrupter release zip file to the microSD card. The firmware file is called "Syntherrupter_Nextion_MODEL.tft". 
* Insert the microSD card into your screen and power it on. The upload starts. 
* It is possible that the upload fails because you actually got a TJC screen, and not a Nextion screen. Try again with the *TJC8048...* firmware instead of the *NX8048...* file. 
* Once the upload has completed, power off your screen and remove the microSD card.

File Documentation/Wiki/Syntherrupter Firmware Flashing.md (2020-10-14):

# Syntherrupter Firmware Flashing

## Index
* [Introduction](#introduction)
* [Note about beta versions](#note-about-beta-versions)
* [Tiva Flashing](#tiva-flashing)
* [Nextion Flashing over USB/Serial](#nextion-flashing-over-usbserial)
* [Nextion Flashing with a microSD card](#nextion-flashing-with-a-microsd-card)

## Introduction
This page covers how to flash a (new) firmware on your Syntherrupter. It requires everything to be wired up as described in the *[Wiring and Schematics](/Documentation/Wiring%20and%20Schematics)* folder.

## Note about beta versions
Beta versions usually include new features that do not touch the core of Syntherrupter. This means it's *highly unlikely* that the update breaks the core's safety features, namely the specified maximum ontime, minimum offtime and maximum duty. However, you should not expect any part of the GUI or any of Syntherrupter's modes to be free of bugs. 

## Tiva Flashing

### Requirements
* Windows. The tools used are not available for other operating systems.
* [Latest Syntherrupter release](https://github.com/MMMZZZZ/Syntherrupter/releases/)
* [Drivers](/Utilities%20and%20Drivers/Tiva%20USB%20Drivers%20(Stellaris%20ICDI%20Drivers).zip?raw=true)
* [LM Flash Programmer](/Utilities%20and%20Drivers/LMFlashProgrammer_1613.msi?raw=true)

### Steps for Driver Installation
* Extract the *stellaris_icdi_drivers* folder from the drivers zip file.
* Connect Tiva LaunchPad to the PC via its DEBUG USB port. 
* Open the Device Manager. One or more unknown "ICDI" devices will be listed. 
* Right click on one of them
	* Choose update the drivers,
	* Search on the PC, 
	* Select the unzipped "stellaris_icdi_drivers". 
	* Repeat for all other unknown "ICDI" devices.

### Steps for Flashing
* Extract the Tiva firmware from the Syntherrupter release zip file. Based on the number of optic transmitters you have, select the right version. The firmware file (for X transmitters) is called "Syntherrupter_Tiva_X_Coils.bin".
* Install and open LM Flash Programmer. 
* On the tab *Configuration*, select *TM4C1294XL LaunchPad* from the *Quick Set* drop down list. 
* Switch to the tab "Program" and select the extracted .bin file.
* Select the following options: 
	* *Erase Entire Flash*
	* *Verify After Program*
	* *Reset MCU After Program*
* Click on *Program* to flash the microcontroller.

## Nextion Flashing over USB/Serial
You can upload a firmware to the Nextion screen using its serial connection. This is very convenient because you don't have to access the microSD card slot on the screen itself. 

Note: While the Nextion screen is configured to communicate at 115200baud/s, the Nextion upload protocol allows to switch to a different baud rate during the firmware upload. The highest possible baud rate is 512000baud/s. This speeds up the upload considerably, "only" taking about 1 minute.

### Requirements
* Windows. The tools used are not available for other operating systems.
* [Tiva Firmware](#tiva-flashing) up and running. 
* [Latest Syntherrupter release](https://github.com/MMMZZZZ/Syntherrupter/releases/)
* [TFTFileDownload](/Utilities%20and%20Drivers/TFTFileDownload.exe?raw=true)

### Steps
* Check the exact model number of your touch screen. 
* Extract the Nextion firmware for your model number from the Syntherrupter release zip file. The firmware file is called "Syntherrupter_Nextion_MODEL.tft". 
* Connect Syntherrupter to your computer and choose *Nextion<->USB* in Syntherrupters *Settings* menu. If your Nextion firmware is not working, the Tiva Firmware will automatically enter this mode after 3 seconds. 
* Open the TFTFileDownload tool and select the COM port. Baud rate should be 512000baud/s. In case you get timeout or other errors, try a lower baud rate. If even at 115200baud/s you can't upload the firmware, there's something wrong.
* Click on the *Down* button to start flashing. 
* Once the upload is done, the screen will reset and stay black until you power cycle Syntherrupter. 

## Nextion Flashing with a microSD card
In case the serial upload does not work or is too slow for you, you can try uploading the firmware using a microSD card. This update method is also useful if you have no access to a Windows PC. 

### Requirements
* [Latest Syntherrupter release](https://github.com/MMMZZZZ/Syntherrupter/releases/)
* microSD card. Note: some microSD cards do not work with the Nextion screen. I cannot tell you if your card will work or not. 

### Steps
* Make sure the microSD card is formatted as FAT32 and empty.
* Check the exact model number of your touch screen. 
* Copy the Nextion firmware for your model number from the Syntherrupter release zip file to the microSD card. The firmware file is called "Syntherrupter_Nextion_MODEL.tft". 
* Insert the microSD card into your screen and power it on. The upload starts. 
* It is possible that the upload fails because you actually got a TJC screen, and not a Nextion screen. Try again with the *TJC8048...* firmware instead of the *NX8048...* file. 
* Once the upload has completed, power off your screen and remove the microSD card.

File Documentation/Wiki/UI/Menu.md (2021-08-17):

# Main Menu

[Back to the User Interface Reference page](README.md#readme)

The main menu is the "root" of the UI. From here you can reach anything. 

## Index
* [Index](#index)
* [What you see](#what-you-see)
* [What you get](#what-you-get)
	* [Simple](#simple)
	* [MIDI Live](#midi-live)
	* [Lightsaber](#lightsaber)
	* [Help and Info](#help-and-info)
	* [Settings](#settings)
	* [Switch User](#switch-user)
* [Sysex Commands](#sysex-commands)

## What you see

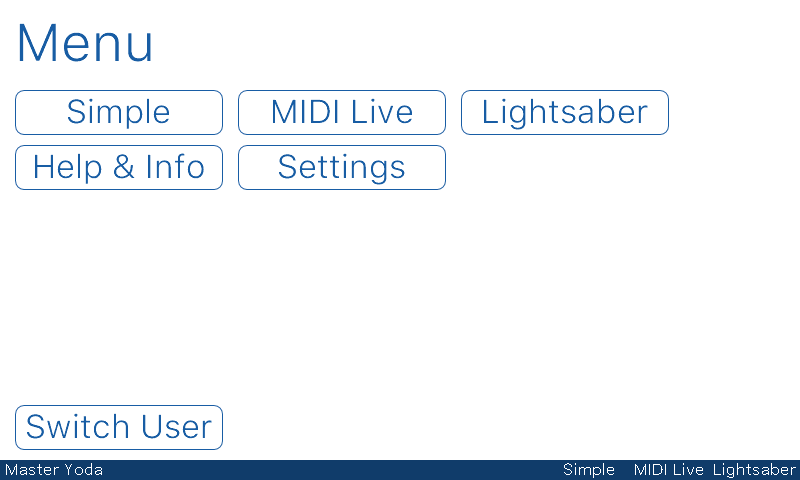
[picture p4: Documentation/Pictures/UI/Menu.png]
Main Menu


## What you get

### Simple

Opens [Simple mode](Simple.md#readme).

### MIDI Live

Opens [MIDI Live mode](MIDI%20Live.md#readme).

### Lightsaber

Opens [Lightsaber mode](Lightsaber.md#readme).

### Help and Info

Shows you the [Help and Info page](Help%20and%20Info.md#readme)

### Settings

Opens the [Settings](Settings.md#readme).

### Switch User

Brings you back to the [Log In page](Log%20In.md#readme). In case you have auto log in set up, this will be disabled now. Otherwise it wouldn't be possible to actually switch the user. 

## Sysex Commands

There are no sysex commands for this specific page. However, only when you're viewing this page (or the [startup screen](Startup.md#readme)), the on-screen data will be updated when receiving sysex commands. If you're f.ex. on the Simple mode page, Syntherrupter will still react and apply all sysex commands, but the values on screen won't follow these changes.

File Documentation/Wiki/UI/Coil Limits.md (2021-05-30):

# Coil Limits

[Back to the User Interface Reference page](README.md#readme)

Description

## Index
* [Index](#index)
* [What you see](#what-you-get)
* [What you get](#what-you-get)
  * [Purpose of Coil Limits](#purpose-of-coil-limits)
  * [Table Layout](#table-layout)
  * [Max Ontime](#max-ontime)
  * [Max Duty Cycle](#max-duty-cycle)
  * [Min Offtime](#min-offtime)
  * [Max MIDI Voices](#max-midi-voices)
  * [Min Ontime](#min-ontime)
* [Sysex Commands](#sysex-commands)

## What you see

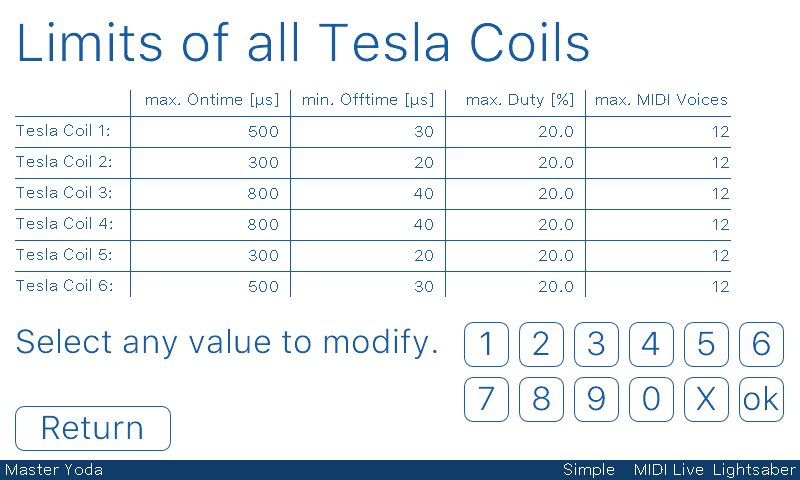
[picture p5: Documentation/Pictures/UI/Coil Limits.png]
Coil Limits


## What you get

### Purpose of Coil Limits

MIDI playback - especially with many simultaneous notes - stresses your coil and with an interrupter like this one it is very easy to to exceed the safe operating area (and the meaningful operating area, too). The individual limits are explained below.

### Table Layout

Each line in the table above contains the limits of one coil. You'll only see lines for the number of coils your firmware supports (depending on [what firmware you flashed lashing](/Documentation/Wiki/Firmware%20Flashing.md#steps-for-flashing)). Each field of the table can be selected by a simple touch, and modified with the keypad. Touching the name or password fields opens a fullsize keyboard. 

### Max Ontime

The maximum ontime simply specifies the longest continuous pulse width that the interrupter will generate on this output. Mostly useful for pulse-skipping coils or coils that won't trip the OCD at a too high ontime. 

The risk of a too high ontime would be to damage your IGBTs because they heat up too far without an offtime to dissipate it. If your bus capacitance is too small, an excessive ontime could also trip the overcurrent protection of your breaker. 

### Max Duty Cycle

For each output and all the voices (from all modes) that currently play on it, Syntherrupter calculates the total duty. Calculating means that Syntherrupter sums up the product of the current frequency and ontime of every voice. Every time one of those parameter changes (f.ex. because of [envelopes]()) the sum gets updated. If the total duty exceeds the maximum duty set here, all ontimes get multiplied by the same factor (notably `max-duty / total-duty`), such that the total duty equals the limit. 

The purpose/benefit of a duty cycle limitation is to limit the RMS current - both in your primary circuit and what you draw from the grid. The first one keeps the temperatures safe (given a high enough RMS current, *every* circuit will overheat), while the second one is important for your fuse box. 

This method has one major drawback. If multiple voices play together, their ontimes are sometimes closer together, sometimes further away. Thus multiple ontimes can and will sit together, causing a momentary duty cycle spike (<1ms). More about this below under [Min Offtime](#min-offtime). Forcibly there must be a duty minimum between those spikes and on average the duty won't exceed the given limit. These grouped ontimes shouldn't be an issue in most cases but their risk is similar to the one of too high ontimes. 

**Important** If you plan on setting a [minimum ontime](#min-ontime), must know that it will be added *after* the duty limiter. With many ontimes (high number of voices and/or high frequencies) this can and will rise the actual output signal's duty cycle beyond the value specified here. Details below.

### Min Offtime

As detailed above, ontimes can and will fall closer together because all the voices will have a totally random phase. This will also lead to ontimes falling one right after the other. Here's the issue: pretty much all drivers turn off at zero crossing but they don't turn on with respect to any (residual) primary current because it's expected to be 0. Some drivers even have startup oscillators that switch a couple times at a fixed frequency without respecting any feedback. Normally these are useful features but in this case it's a danger. If two ontimes are too close together, the second one starts before your primary current was able to ring down. Thus you risk hard switching with significant amounts of primary current and in consequence the destruction of your bridge. 

The solution is to introduce a minimum offtime after each ontime. This value has a strong impact on the sound quality (try it out; too big values won't do any other damage), therefore it should be chosen as small as possible. The current doesn't need to ring down completely; after all the bricks were originally manufactured for some amount of hardswitching. If you have really no idea what value you should enter here, take your scope and look how long the primary current needs to get to 0 (I suggest you do this using [Simple Mode](Simple.md#readme). That value will for sure be enough. Next step could be to slowly reduce it while montioring bridge current and voltage. This obviously needs to be done in MIDI Live Mode with more than one active voice. I suggest you set up your scope to trigger on offtimes smaller than X such that you'll only see the interesting cases. Stop when you see excessive voltage spikes or you notice a temperature rise of your bricks.

### Max MIDI Voices

Syntherrupter is able to handle a crazy amount of simultaneous voices (well over 30 - more than you can play in a meaningful way on 6 coils). Since [MIDI Live Mode](MIDI%20Live.md#readme) is the only polyphonic mode (= the only mode contributing more than 1 voice), it makes sence to limit how many voices it'll generate. This limit can be adjusted from 1 to 16 for each coil. 

MIDI Live Mode itself has a global list of currently active notes - independently of what your coil and channel settings are. This list can take up to 64 notes. Then, based on your channel and stereo settings, some of these notes will be forwarded to each coil's output - starting with the most recent note and up to the limit specified here. This allows you f.ex. to play with a sustain pedal that'll quickly raise the number of simultaneous notes beyond this limit. Since internally the notes are still tracked, you can lift the pedal and still hear the notes that were kept pressed. There are other useful cases, too, if this one is not relatable.

This limit is not directly safety relevant but it still is a very useful limitation. Depending on your coil (high/low impedance, big/smal, pulse-skipping, ...) a different number of voices are acceptable and more voices would rather decrease than increase the sound quality. Once again something to experiment with - if you find a MIDI file with that many voices (<= guess you could call that first-interrupter-world-problems). 

### Min Ontime

This parameter cannot be modified through the UI but only via [Sysex Commands](#sysex-commands). It is however stored in EEPROM just like any other command (either by using the [EEPROM Update Sysex command](Custom%20MIDI%20Commands.md#0x200-0x21f-eeprom-and-other-control-commands) or by hitting [Settings->Save](Settings.md#savereturn-to-main-menu).

Most coils - especially those that operate at the lower pole - require a minimum amount of primary current before any output is generated. The relation between ontime and output (volume) is thus not linear but has an offset. This has a very strong impact on the audio quality; low volume notes (fade in / fade out) won't generate any output, thus not be audible. Fadings sound weird, too, because parts of them miss. 

All of Syntherrupters effects are based on a linear relationship. To "fix" this, a offset ontime will be added to *every* ontime of every mode. A fade in of lets say 0us to 20us would generate an ouput signal of 30us to 50us (with min ontime set to 30us). 

This minimum/offset ontime is added *after* applying the duty limitation for technical reasons, but *before* the ontime limitation. It doesn't affect the minimum offtime either. The obvious consequence is that the minimum ontime causes the output signal to raise beyond the duty limit when (or even though) the duty cycle limiter is active. However, the minimum ontime usually covers only a small part of your primary current ring up. Thus the stress on your parts is lower than with a "normal" or "full" ontime. Another consequence of this design choice is that even if the duty limiter is active, the sound quality is not affected; no effect will suffer from dropping below the minimum ontime. 

## Sysex Commands

All of the settings above can be controlled by the [Coil Settings](/Documentation/Wiki/Custom%20MIDI%20Commands.md#0x260-0x27f-coil-settings) group of the sysex commands.

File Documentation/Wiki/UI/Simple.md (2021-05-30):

# Simple Mode

[Back to the User Interface Reference page](README.md#readme)

Simple mode allows you to generate classic, single tone interrupter signals. You have control over ontime, BPS and duty of the signal. Simple mode includes a slight filter that causes a smooth transition when changing any of the settings. As of now this cannot be disabled or modified without recompiling.

## Index
* [Index](#index)
* [What you see](#what-you-see)
* [What you get](#what-you-get)
	* [Ontime](#ontime)
	* [BPS](#bps)
	* [Duty](#duty)
	* [Apply to Outputs](#apply-to-outputs)
	* [Applying Manually, On Release or Immediately](#applying-manually-on-release-or-immediately)
	* [Return to Main Menu](#return-to-main-menu)
* [Sysex Commands](#sysex-commands)

## What you see

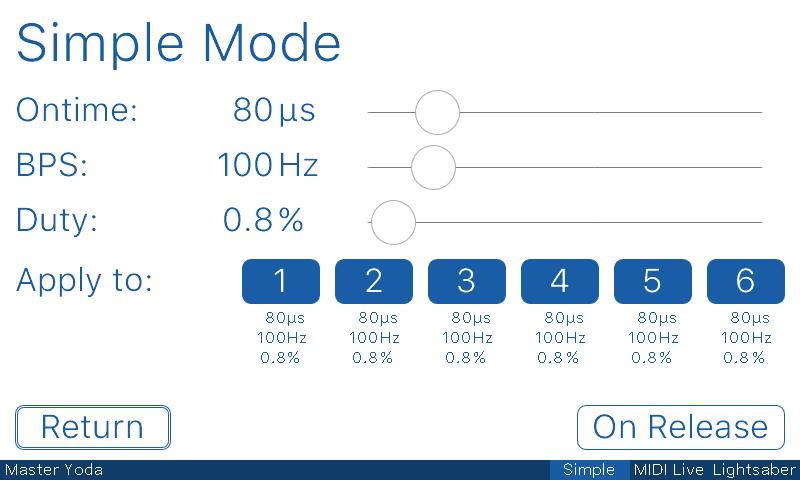
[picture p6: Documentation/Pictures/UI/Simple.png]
Simple Mode


## What you get

### Ontime

Using the slider you can vary the ontime within the [user's limits](Users.md#readme). 

Any change automatically updates the duty value, too.

### BPS

Using the slider you can vary the BPS (Bans Per Second, frequency) within the [user's limits](Users.md#readme).

Any change automatically updates the ontime or duty value, too. Your most recent change will be preserved. For example: if you set the ontime, then adjust the BPS, you ontime setting will be preserved and the duty value adjusted according to your changes. 

### Duty

Using the slider you can vary the duty cycle within the [user's limits](Users.md#readme).

Any change automatically updates the ontime value, too.

### Apply to Outputs

This part of the UI is only visible if you have more than one output. 

Each output is represented by a button. This button doesn't show whether the output is active, but whether your next change will affect this output. If you want to change the outputs 1 and 3 you select these two, and deselect all the other outputs. Any change you make will only affect those two outputs. The others continue to operate on whatever settings they currentley are.

Since it is hard to remember 6 sets of ontime and BPS (and duty), the currently active values are displayed below each button. 

Unlike the values displayed in [MIDI Live mode](MIDI%20Live.md#apply-to-outputs-and-midi-coil-settings), these values do respect the [Coil Limits](Coil%20Limits.md#readme). Here it makes sence because you'll see your settings 1:1 on the output(s); there are no musical effects. 

### Applying Manually, On Release or Immediately

*This section applies equally to all modes (Simple, [MIDI Live](MIDI%20Live.md#readme) and [Lightsaber](Lightsaber.md#readme)). Hence you may have been redirected to this section from a different mode.*

By default new values are applied *On Release* to the selected outputs, meaning that they get applied as soon as you release any of the three sliders. 

Pressing the *On Release* button will change the mode to *Manually* and another button appears: *Apply Now*. This gives the user the control when exactly he wants to apply new settings and allows f.ex. to change multiple values at the same time. 

Pressing the *Manually* button changes the mode again. The third and last mode applies changes *Immediately*. This means that your slider movement will affect the outputs in real time. 

### Return to Main Menu

*This section applies equally to all modes (Simple, [MIDI Live](MIDI%20Live.md#readme) and [Lightsaber](Lightsaber.md#readme). Hence you may have been redirected to this section from a different mode.*

A simple press of the *Return* button stops Simple mode and brings the user back to the [Main Menu](Menu.md#readme). 

Keeping the button pressed brings the user back to the [Main Menu](Menu.md#readme), too. However, Simple mode won't be stopped. It continues to run in the background. There are no limitations to this feature. Any combination of modes can run simultaneously.

## Sysex Commands

Ontime and active outputs can be controller by the [Common Mode Parameters](/Documentation/Wiki/Custom%20MIDI%20Commands.md#0x20-0x3f-common-mode-parameters) group of the sysex commands. 

Simple mode specific settings are available through the [Simple Mode Parameters](/Documentation/Wiki/Custom%20MIDI%20Commands.md#0x40-0x5f-simple-mode-parameters) group of the sysex commands.

The apply mode can be changed using the [UI Settings](/Documentation/Wiki/Custom%20MIDI%20Commands.md#0x220-0x23f-ui-settings) sysex commands.

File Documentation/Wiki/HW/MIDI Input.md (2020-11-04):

# MIDI Input Jack

[Back to the hardware documentation overview](README.md#readme)

If you want to receive MIDI data using the standard 5-pin DIN connector, you'll need to add the according jack for it. 

## Communication Pin

* Tiva PC4: MIDI In

## Schematic

The following schematic of a "complete" Syntherrupter shows the circuitry needed to receive MIDI data. The way how the transmission works makes it mandatory to use an optocoupler on the receiver side. R13 is not critical and can be pretty much anything from 1k to 10k.

Complete Schematic

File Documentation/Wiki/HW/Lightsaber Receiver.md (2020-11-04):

# Lightsaber Receiver

[Back to the hardware documentation overview](README.md#readme)

The Lightsaber feature is based on the ESP8266. To flash them and to receive data in normal operation you need to be able to connect them to the Tiva LaunchPad. 

To see how to build the Lightsabers themselves, please have a look at the pictures in the following [folder](/Documentation/Wiring%20and%20Schematics/Lightsaber%20Sender).

## Communication Pins

* Tiva PA6: ESP GPIO1 (U0TX)
* Tiva PA7: ESP GPIO3 (U0RX)

## Schematic and Pinout

The following schematic of a "complete" Syntherrupter shows at the bottom right how to connect the ESP8266 to the Tiva LaunchPad. Note that you need some kind of switch for GPIO2. When powering up the ESP this pin determines if it can be flashed or if it operates normally. Since you need to flash all ESPs I suggest to include a female pin header for connecting the ESPs. 

Complete Schematic

ESP-01 Pinout: 

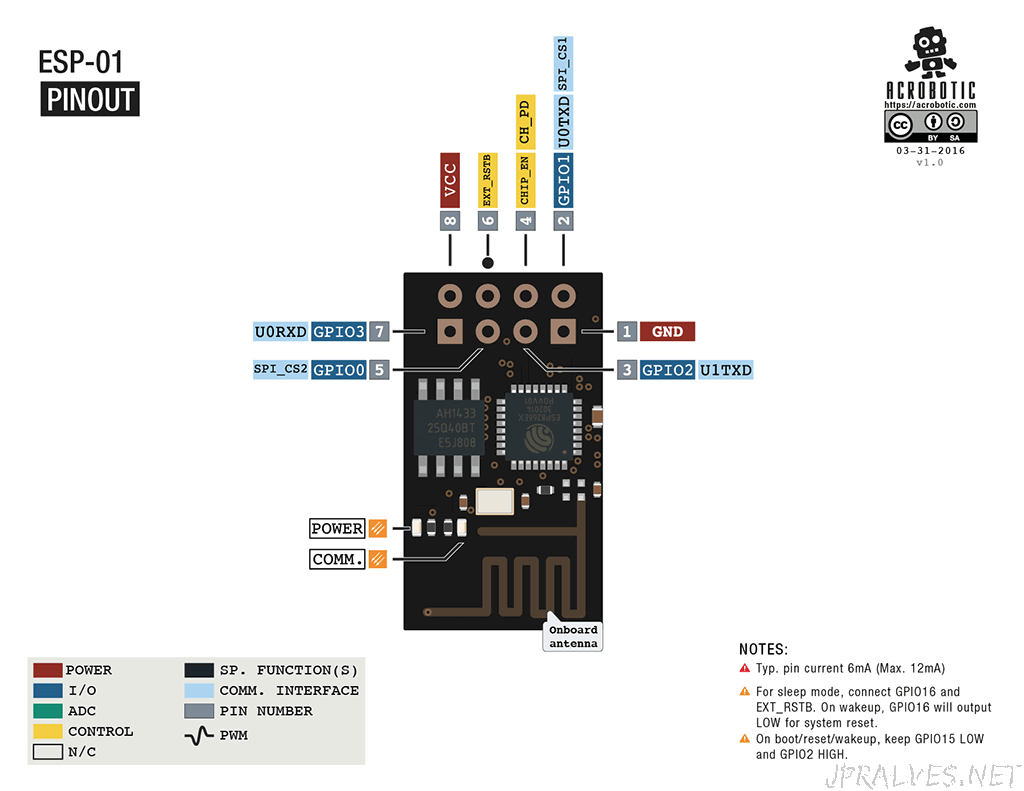
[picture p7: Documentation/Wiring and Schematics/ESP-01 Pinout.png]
ESP-01 Pinout


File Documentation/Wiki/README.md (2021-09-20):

# Syntherrupter Wiki

Welcome to the Syntherrupter wiki. This is a collection of how-tos and documentation around Syntherrupter. 

## Content

* **[Getting Started](Getting%20Started.md#readme). Start here if you're new.** 
* [Firmware Flashing](Firmware%20Flashing.md#readme). How to flash Syntherrupter for the first time or update its firmware.
* [Password Reset](Password%20Reset.md#readme). Forgot your password or need to reset it? Here's how you do it.
* [Lightsaber ESP8266 Setup](Lightsaber%20ESP8266%20Setup.md#readme). How to flash and use the ESP8266 which the lightsabers are based on.
* [Hardware Reference](HW/README.md#readme). Schematics, parts, wiring, etc.
* [User Interface Reference](UI/README.md#readme). Documentation of all UI features and functions.
* [Custom MIDI Commands](Custom%20MIDI%20Commands.md#readme). Documentation of the Syntherrupter specific commands, that are f.ex. required for some stereo features.
* [Build-in Envelopes](Envelopes.md#readme). List of the build-in envelopes and how to use them.

## External Content

The High Voltage Forum topic contains some subjects that haven't made their way into this wiki yet. Hence they're linked below. 

* [My best MIDI sources](https://highvoltageforum.net/index.php?topic=1020.msg8661#msg8661). Somewhat outdated but still useful I guess.
* [A bunch of demo videos with a tesla coil](https://highvoltageforum.net/index.php?topic=1020.msg9299#msg9299). Thanks futurist! And just below that post you'll find a video from AstRii, too.
* [What the n-tau parameter does to envelopes (ADSR)](https://highvoltageforum.net/index.php?topic=1020.msg8850#msg8850). Post is outdated, picture not.
* [Envelope (ADSR) editor and looping](https://highvoltageforum.net/index.php?topic=1020.msg9082#msg9082)
* [What is MIDI? What is ADSR? Is it the same?](https://highvoltageforum.net/index.php?topic=1020.msg9120#msg9120)
* [In-depth explanation of note duty vs note ontime](https://highvoltageforum.net/index.php?topic=1020.msg8564#msg8564)
* [AstRiis Syntherrupter build with 4 outputs](https://highvoltageforum.net/index.php?topic=1267.msg9292#msg9292)

In addition, Mads Barnkob from [Kaizer Power Electronics](https://kaizerpowerelectronics.dk/) has a video series about his impressive Syntherrupter based show controller:

* [Tesla Coil Show Controller Project (Part 1 of 6)](https://www.youtube.com/watch?v=Ad2129sZv6w)
* [Tesla Coil Show Controller - Programming Syntherrupter (Part 2 of 6)](https://www.youtube.com/watch?v=jQZj8DPNvJg)
* [Tesla Coil Show Controller - 6 Optical Output Control Panel (Part 3 of 6)](https://www.youtube.com/watch?v=DCFt82_SrNI)
* [Tesla Coil Show Controller - 6 Interrupters (Part 4 of 8)](https://www.youtube.com/watch?v=pOEmQ9KFFWY)
* [Tesla Coil Show Controller - Syntherrupter Installation And MIDI Test (Part 5 of 8)](https://www.youtube.com/watch?v=JB4-n_mJty4)
* *(Other parts will be added as soon as they're released)*

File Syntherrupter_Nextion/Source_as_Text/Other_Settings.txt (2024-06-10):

Page Other_Settings
    Attributes
        ID               : 0
        Scope            : local
        Send Component ID: disabled
        Locked           : no
    
    Events
        Preinitialize Event
            // Prevent page refreshs until postinit
            ref_stop
            //
            // Load colors
            click fLoadColors,1
            click fLoadModes,1
            //
            // Display username
            if(User_Settings.userNum.val==0)
            {
                tUser.txt=" "+User_Settings.u0Name.txt
            }else if(User_Settings.userNum.val==1)
            {
                tUser.txt=" "+User_Settings.u1Name.txt
            }else if(User_Settings.userNum.val==2)
            {
                tUser.txt=" "+User_Settings.u2Name.txt
            }
            //
            vis fLoadModes,0
            vis fLoadColors,0
            vis idle,0
            vis fCheckNApply,0
            vis fSqrt,0
            vis fSysex,0
            //
            // Properly hide the help stuff.
            vis hHelp,0
            vis tHelp,0
            //
            tSave.bco=Settings.backSelectCol2.val
            vis tSave,Settings.unsaved.val
            //
            newValTargetId.val=idle.id
            //
            // Load settings from global variables.
            btDark.val=Settings.colorMode.val
            fSqrt.val=dim*sBrightness.maxval
            click fSqrt,1
            sBrightness.val=fSqrt.val
            sys0=thsp
            nSleepMin.val=sys0/60
            sys1=nSleepMin.val*60
            sys0-=sys1
            nSleepS.val=sys0
            nHoldTime.val=holdTime.val
            nBackOff.val=backOff.val
            //
            // Enable page refreshs again
            ref_star
        
        Postinitialize Event
            //
            // Calculate original state of all variables to be able to determine if something has changed.
            click fCRC,1
            originalState.val=crcval
        
        Touch Press Event
            if(Other_Settings.backOff.val!=0)
            {
                // Default "stop" action.
                // Set ontime and duty to 0 for all modes. See fSysex for details
                // Disable all modes as well.
                printh f0 00 26 05 01 7f 20 00 00 7f 00 00 00 00 00 f7
                printh f0 00 26 05 01 7f 21 00 00 7f 00 00 00 00 00 f7
                printh f0 00 26 05 01 7f 22 00 00 7f 00 00 00 00 00 f7
                // Set all ontime and duty settings of all pages to 0.
                // First come the global variables then the local variables.
                Simple.ontime.val=0
                Simple.duty.val=0
                Simple.set1.val=Simple.set1.val&0x0000ffff
                Simple.set2.val=Simple.set2.val&0x0000ffff
                Simple.set3.val=Simple.set3.val&0x0000ffff
                Simple.set4.val=Simple.set4.val&0x0000ffff
                Simple.set5.val=Simple.set5.val&0x0000ffff
                Simple.set6.val=Simple.set6.val&0x0000ffff
                MIDI_Live.ontime.val=0
                MIDI_Live.duty.val=0
                MIDI_Live.set1.val=0
                MIDI_Live.set2.val=0
                MIDI_Live.set3.val=0
                MIDI_Live.set4.val=0
                MIDI_Live.set5.val=0
                MIDI_Live.set6.val=0
                Lightsaber.ontime.val=0
                Lightsaber.ontimes12.val=0
                Lightsaber.ontimes34.val=0
                Lightsaber.ontimes56.val=0
            }
        
Variable (int32) newValTargetId
    Attributes
        ID   : 12
        Scope: local
        Value: 20
    
Variable (int32) newSelect
    Attributes
        ID   : 13
        Scope: local
        Value: 0
    
Variable (int32) currentHelp
    Attributes
        ID   : 43
        Scope: local
        Value: 4294967295
    
Variable (int32) originalState
    Attributes
        ID   : 45
        Scope: local
        Value: 0
    
Variable (int32) holdTime
    Attributes
        ID   : 49
        Scope: global
        Value: 250
    
Variable (int32) backOff
    Attributes
        ID   : 50
        Scope: global
        Value: 1
    
Number nHoldTime
    Attributes
        ID                 : 11
        Scope              : local
        Send Component ID  : disabled
        Associated Keyboard: none
        Value              : 250
    
    Events
        Touch Press Event
            // Check if values are legal and if so, apply them
            click fCheckNApply,0
            // Reset push state of last selected value
            b[newValTargetId.val].bco=idle.bco
            b[newValTargetId.val].pco=idle.pco
            // Mark this field as pushed
            nHoldTime.bco=idle.pco
            nHoldTime.pco=idle.bco
            newValTargetId.val=nHoldTime.id
            // A new value has been selected
            newSelect.val=1
        
Number nSleepMin
    Attributes
        ID                 : 31
        Scope              : local
        Send Component ID  : disabled
        Associated Keyboard: none
        Value              : 5
    
    Events
        Touch Press Event
            // Check if values are legal and if so, apply them
            click fCheckNApply,0
            // Reset push state of last selected value
            b[newValTargetId.val].bco=idle.bco
            b[newValTargetId.val].pco=idle.pco
            // Mark this field as pushed
            nSleepMin.bco=idle.pco
            nSleepMin.pco=idle.bco
            newValTargetId.val=nSleepMin.id
            // A new value has been selected
            newSelect.val=1
        
Number nSleepS
    Attributes
        ID                 : 32
        Scope              : local
        Send Component ID  : disabled
        Associated Keyboard: none
        Value              : 30
    
    Events
        Touch Press Event
            // Check if values are legal and if so, apply them
            click fCheckNApply,0
            // Reset push state of last selected value
            b[newValTargetId.val].bco=idle.bco
            b[newValTargetId.val].pco=idle.pco
            // Mark this field as pushed
            nSleepS.bco=idle.pco
            nSleepS.pco=idle.bco
            newValTargetId.val=nSleepS.id
            // A new value has been selected
            newSelect.val=1
        
Number fSqrt
    Attributes
        ID                 : 36
        Scope              : local
        Send Component ID  : disabled
        Associated Keyboard: none
        Value              : 0
    
    Events
        Touch Press Event
            // fXxxx are functions. Since they need to be clicked to execute their code they need to be on the same page. Usage:
            // 1. set the component value (fXxx.val) to the input value
            // 2. Execute code with "click fXxxx,1".
            // 3. Read the result from the component value (fXxx.val)
            // This functions calculates the square root.
            if(fSqrt.val>=2)
            {
                sys0=10
                sys2=fSqrt.val+1
                while(sys2>fSqrt.val)
                {
                    sys1=fSqrt.val/sys0
                    sys0+=sys1
                    sys0/=2
                    sys2=sys0*sys0
                }
                fSqrt.val=sys0
            }
        
Number nBackOff
    Attributes
        ID                 : 38
        Scope              : local
        Send Component ID  : disabled
        Associated Keyboard: none
        Value              : 1
    
    Events
        Touch Press Event
            // Check if values are legal and if so, apply them
            click fCheckNApply,0
            // Reset push state of last selected value
            b[newValTargetId.val].bco=idle.bco
            b[newValTargetId.val].pco=idle.pco
            // Mark this field as pushed
            nBackOff.bco=idle.pco
            nBackOff.pco=idle.bco
            newValTargetId.val=nBackOff.id
            // A new value has been selected
            newSelect.val=1
        
XFloat idle
    Attributes
        ID                 : 14
        Scope              : local
        Send Component ID  : disabled
        Associated Keyboard: none
        Value              : 0
    
Text tUser
    Attributes
        ID                 : 1
        Scope              : local
        Send Component ID  : disabled
        Associated Keyboard: none
        Text               :  Guest
        Max. Text Size     : 32
    
    Events
        Touch Press Event
            // Make this object "transparent" for clicks and click background.
            click 0,1
        
Text tMSI
    Attributes
        ID                 : 2
        Scope              : local
        Send Component ID  : disabled
        Associated Keyboard: none
        Text               : Simple
        Max. Text Size     : 16
    
    Events
        Touch Press Event
            // Make this object "transparent" for clicks and click background.
            click 0,1
        
Text tMML
    Attributes
        ID                 : 3
        Scope              : local
        Send Component ID  : disabled
        Associated Keyboard: none
        Text               : MIDI Live
        Max. Text Size     : 16
    
    Events
        Touch Press Event
            // Make this object "transparent" for clicks and click background.
            click 0,1
        
Text tMLS
    Attributes
        ID                 : 4
        Scope              : local
        Send Component ID  : disabled
        Associated Keyboard: none
        Text               : Lightsaber
        Max. Text Size     : 16
    
    Events
        Touch Press Event
            // Make this object "transparent" for clicks and click background.
            click 0,1
        
Text tSave
    Attributes
        ID                 : 5
        Scope              : local
        Send Component ID  : disabled
        Associated Keyboard: none
        Text               : Unsaved Settings!
        Max. Text Size     : 40
    
    Events
        Touch Press Event
            // Make this object "transparent" for clicks and click background.
            click 0,1
        
Text tHelp
    Attributes
        ID                 : 6
        Scope              : local
        Send Component ID  : disabled
        Associated Keyboard: none
        Text               : 
        Max. Text Size     : 900
    
    Events
        Touch Press Event
            // This object is only visible in help mode. No need to be "transparent" to clicks in normal operation.
            click bReturn,0
        
Text tHideBack
    Attributes
        ID                 : 7
        Scope              : local
        Send Component ID  : disabled
        Associated Keyboard: none
        Text               :  
        Max. Text Size     : 1
    
    Events
        Touch Press Event
            // This is just to hide the background around the sliders so that you do not turn the outputs off by accident.
        
Text tTitle
    Attributes
        ID                 : 8
        Scope              : local
        Send Component ID  : disabled
        Associated Keyboard: none
        Text               : General Settings
        Max. Text Size     : 22
    
    Events
        Touch Press Event
            // Make this object "transparent" for clicks and click background.
            click 0,1
        
Text tHoldTime
    Attributes
        ID                 : 10
        Scope              : local
        Send Component ID  : disabled
        Associated Keyboard: none
        Text               : Button hold Time:
        Max. Text Size     : 30
    
    Events
        Touch Press Event
            // Make this object "transparent" for clicks and click background.
            click 0,1
        
Text tBrightness
    Attributes
        ID                 : 27
        Scope              : local
        Send Component ID  : disabled
        Associated Keyboard: none
        Text               : Display brightness:
        Max. Text Size     : 30
    
    Events
        Touch Press Event
            // Make this object "transparent" for clicks and click background.
            click 0,1
        
Text fCheckNApply
    Attributes
        ID                 : 29
        Scope              : local
        Send Component ID  : disabled
        Associated Keyboard: none
        Text               :  
        Max. Text Size     : 10
    
    Events
        Touch Release Event
            // Settings must stay in certain ranges. this function checks and fixes them.Afterwards settings are applied
            if(nBackOff.val!=0)
            {
                nBackOff.val=1
            }
            backOff.val=nBackOff.val
            if(nHoldTime.val<50)
            {
                // Hold time must at least be 50ms. This is the lower limit of the nextion timer object
                nHoldTime.val=50
            }else if(nHoldTime.val>9999)
            {
                // Who would want to push a button 10s or more??
                nHoldTime.val=9999
            }
            holdTime.val=nHoldTime.val
            if(nSleepMin.val>60)
            {
                nSleepMin.val=60
            }
            if(nSleepS.val>59)
            {
                nSleepS.val=59
            }
            thsp=nSleepMin.val*60+nSleepS.val
            //
            // Check if something has actually been changed
            click fCRC,1
            if(crcval!=originalState.val)
            {
                Settings.unsaved.val=1
                click fSysex,1
            }
            vis tSave,Settings.unsaved.val
        
Text tSleep
    Attributes
        ID                 : 30
        Scope              : local
        Send Component ID  : disabled
        Associated Keyboard: none
        Text               : Enter sleep after:
        Max. Text Size     : 30
    
    Events
        Touch Press Event
            // Make this object "transparent" for clicks and click background.
            click 0,1
        
Text tMin
    Attributes
        ID                 : 33
        Scope              : local
        Send Component ID  : disabled
        Associated Keyboard: none
        Text               : min
        Max. Text Size     : 3
    
    Events
        Touch Press Event
            // Make this object "transparent" for clicks and click background.
            click 0,1
        
Text tS
    Attributes
        ID                 : 34
        Scope              : local
        Send Component ID  : disabled
        Associated Keyboard: none
        Text               : s
        Max. Text Size     : 3
    
    Events
        Touch Press Event
            // Make this object "transparent" for clicks and click background.
            click 0,1
        
Text tms
    Attributes
        ID                 : 35
        Scope              : local
        Send Component ID  : disabled
        Associated Keyboard: none
        Text               : ms
        Max. Text Size     : 2
    
    Events
        Touch Press Event
            // Make this object "transparent" for clicks and click background.
            click 0,1
        
Text tBackOff
    Attributes
        ID                 : 37
        Scope              : local
        Send Component ID  : disabled
        Associated Keyboard: none
        Text               : Background shutdown:
        Max. Text Size     : 30
    
    Events
        Touch Press Event
            // Make this object "transparent" for clicks and click background.
            click 0,1
        
Text tSelToMod
    Attributes
        ID                 : 40
        Scope              : local
        Send Component ID  : disabled
        Associated Keyboard: none
        Text               : Select any value to modify.
        Max. Text Size     : 30
    
    Events
        Touch Press Event
            // Make this object "transparent" for clicks and click background.
            click 0,1
        
Slider sBrightness
    Attributes
        ID               : 28
        Scope            : local
        Send Component ID: disabled
        Position         : 100
        Upper range limit: 100
        Lower range limit: 10
    
    Events
        Touch Press Event
            // Check if (previously set) values are legal and if so, apply them
            click fCheckNApply,0
            // Reset push state of last selected value
            b[newValTargetId.val].bco=idle.bco
            b[newValTargetId.val].pco=idle.pco
            // No value selected to modify
            newValTargetId.val=idle.id
            // A new value has been selected
            newSelect.val=0
        
        Touch Release Event
            sys0=sBrightness.val*sBrightness.val
            sys0/=sBrightness.maxval
            dim=sys0
            // Check if (previously set) values are legal and if so, apply them
            click fCheckNApply,0
        
Button bReturn
    Attributes
        ID               : 9
        Scope            : local
        Send Component ID: disabled
        State            : unpressed
        Text             : â†
        Max. Text Size   : 10
    
    Events
        Touch Press Event
            click bOK,0
        
        Touch Release Event
            page Settings
        
Button b0
    Attributes
        ID               : 15
        Scope            : local
        Send Component ID: disabled
        State            : unpressed
        Text             : 0
        Max. Text Size   : 1
    
    Events
        Touch Release Event
            if(newSelect.val!=0)
            {
                newSelect.val=0
                b[newValTargetId.val].val=0
            }else
            {
                b[newValTargetId.val].val*=10
            }
        
Button b1
    Attributes
        ID               : 16
        Scope            : local
        Send Component ID: disabled
        State            : unpressed
        Text             : 1
        Max. Text Size   : 1
    
    Events
        Touch Release Event
            if(newSelect.val!=0)
            {
                newSelect.val=0
                b[newValTargetId.val].val=0
            }else
            {
                b[newValTargetId.val].val*=10
            }
            b[newValTargetId.val].val+=1
        
Button b2
    Attributes
        ID               : 17
        Scope            : local
        Send Component ID: disabled
        State            : unpressed
        Text             : 2
        Max. Text Size   : 1
    
    Events
        Touch Release Event
            if(newSelect.val!=0)
            {
                newSelect.val=0
                b[newValTargetId.val].val=0
            }else
            {
                b[newValTargetId.val].val*=10
            }
            b[newValTargetId.val].val+=2
        
Button b3
    Attributes
        ID               : 18
        Scope            : local
        Send Component ID: disabled
        State            : unpressed
        Text             : 3
        Max. Text Size   : 1
    
    Events
        Touch Release Event
            if(newSelect.val!=0)
            {
                newSelect.val=0
                b[newValTargetId.val].val=0
            }else
            {
                b[newValTargetId.val].val*=10
            }
            b[newValTargetId.val].val+=3
        
Button b4
    Attributes
        ID               : 19
        Scope            : local
        Send Component ID: disabled
        State            : unpressed
        Text             : 4
        Max. Text Size   : 1
    
    Events
        Touch Release Event
            if(newSelect.val!=0)
            {
                newSelect.val=0
                b[newValTargetId.val].val=0
            }else
            {
                b[newValTargetId.val].val*=10
            }
            b[newValTargetId.val].val+=4
        
Button b5
    Attributes
        ID               : 20
        Scope            : local
        Send Component ID: disabled
        State            : unpressed
        Text             : 5
        Max. Text Size   : 1
    
    Events
        Touch Release Event
            if(newSelect.val!=0)
            {
                newSelect.val=0
                b[newValTargetId.val].val=0
            }else
            {
                b[newValTargetId.val].val*=10
            }
            b[newValTargetId.val].val+=5
        
Button b6
    Attributes
        ID               : 21
        Scope            : local
        Send Component ID: disabled
        State            : unpressed
        Text             : 6
        Max. Text Size   : 1
    
    Events
        Touch Release Event
            if(newSelect.val!=0)
            {
                newSelect.val=0
                b[newValTargetId.val].val=0
            }else
            {
                b[newValTargetId.val].val*=10
            }
            b[newValTargetId.val].val+=6
        
Button b7
    Attributes
        ID               : 22
        Scope            : local
        Send Component ID: disabled
        State            : unpressed
        Text             : 7
        Max. Text Size   : 1
    
    Events
        Touch Release Event
            if(newSelect.val!=0)
            {
                newSelect.val=0
                b[newValTargetId.val].val=0
            }else
            {
                b[newValTargetId.val].val*=10
            }
            b[newValTargetId.val].val+=7
        
Button b8
    Attributes
        ID               : 23
        Scope            : local
        Send Component ID: disabled
        State            : unpressed
        Text             : 8
        Max. Text Size   : 1
    
    Events
        Touch Release Event
            if(newSelect.val!=0)
            {
                newSelect.val=0
                b[newValTargetId.val].val=0
            }else
            {
                b[newValTargetId.val].val*=10
            }
            b[newValTargetId.val].val+=8
        
Button b9
    Attributes
        ID               : 24
        Scope            : local
        Send Component ID: disabled
        State            : unpressed
        Text             : 9
        Max. Text Size   : 1
    
    Events
        Touch Release Event
            if(newSelect.val!=0)
            {
                newSelect.val=0
                b[newValTargetId.val].val=0
            }else
            {
                b[newValTargetId.val].val*=10
            }
            b[newValTargetId.val].val+=9
        
Button bClear
    Attributes
        ID               : 25
        Scope            : local
        Send Component ID: disabled
        State            : unpressed
        Text             : X
        Max. Text Size   : 1
    
    Events
        Touch Release Event
            b[newValTargetId.val].val=0
        
Button bOK
    Attributes
        ID               : 26
        Scope            : local
        Send Component ID: disabled
        State            : unpressed
        Text             : ok
        Max. Text Size   : 2
    
    Events
        Touch Release Event
            b[newValTargetId.val].bco=idle.bco
            b[newValTargetId.val].pco=idle.pco
            newValTargetId.val=idle.id
            click fCheckNApply,0
        
Dual-state Button btDark
    Attributes
        ID               : 39
        Scope            : local
        Send Component ID: disabled
        State            : unpressed
        Text             : Dark Mode
        Max. Text Size   : 20
    
    Events
        Touch Release Event
            // REMEMBER TO CHANGE Tiva settings loading code!
            if(Settings.colorMode.val==0)
            {
                Settings.colorMode.val=1
                Settings.backCol.val=Settings.CM1backCol.val
                Settings.backCol2.val=Settings.CM1backCol2.val
                Settings.backSelectCol2.val=Settings.CM1backSelCol2.val
                Settings.frontCol.val=Settings.CM1frontCol.val
                Settings.frontCol2.val=Settings.CM1frontCol2.val
            }else
            {
                Settings.colorMode.val=0
                Settings.backCol.val=Settings.CM0backCol.val
                Settings.backCol2.val=Settings.CM0backCol2.val
                Settings.backSelectCol2.val=Settings.CM0backSelCol2.val
                Settings.frontCol.val=Settings.CM0frontCol.val
                Settings.frontCol2.val=Settings.CM0frontCol2.val
            }
            click bOK,0
            page dp
        
Dual-state Button btHelp
    Attributes
        ID               : 44
        Scope            : local
        Send Component ID: disabled
        State            : unpressed
        Text             : ?
        Max. Text Size   : 1
    
    Events
        Touch Release Event
            if(btHelp.val==0)
            {
                // In case something was displayed, get rid of it
                bReturn.val=1
                click hHelp,0
                // disable help overlay
                vis hHelp,0
            }else
            {
                vis hHelp,1
            }
        
Hotspot fLoadModes
    Attributes
        ID               : 41
        Scope            : local
        Send Component ID: disabled
    
    Events
        Touch Press Event
            // Load active modes
            sys0=Settings.activeModes.val&4
            if(sys0!=0)
            {
                // Lightsaber Mode is active
                tMLS.bco=Settings.backSelectCol2.val
            }
            //
            // Display all active modes
            sys0=Settings.activeModes.val&1
            if(sys0!=0)
            {
                // Simple Mode is active
                tMSI.bco=Settings.backSelectCol2.val
            }
            sys0=Settings.activeModes.val&2
            if(sys0!=0)
            {
                // MIDI Live Mode is active
                tMML.bco=Settings.backSelectCol2.val
            }
        
Hotspot fSysex
    Attributes
        ID               : 42
        Scope            : local
        Send Component ID: disabled
    
    Events
        Touch Press Event
            // Sends a Syntherrupter Sysex command that updates Syntherrupter with whatever
            // has been changed on this page.
            // Package format:
            // F0 00 DMID DMID VERSION DEVICE PN_LSB PN_MSB TG_LSB TG_MSB VAL_LSB VAL VAL VAL VAL_MSB F7
            // DMID DMID = 26 05
            // VERSION = 01
            // DEVICE = 7f (wildcard)
            // PN, TG, VAL: see syntherrupter sysex documentation
            //
            //
            // Display Brightness
            // SYSEX_START DMID VERSION DEVICE
            printh f0 00 26 05 01 7f
            // PN_LSB PN_MSB
            printh 20 02 // Display Brightness
            // TG_LSB
            printh 00 // Reserved
            // TG_MSB
            printh 00 // Reserved
            // VAL (4 bytes to be packed into 5 groups of 7 bit)
            // Brightness: 0-100
            prints dim,1
            // Brightness uses less than 7 bits, hardcode remaining bytes.
            printh 00 00 00 00
            // SYSEX_END
            printh f7
            //
            // Standby
            // SYSEX_START DMID VERSION DEVICE
            printh f0 00 26 05 01 7f
            // PN_LSB PN_MSB
            printh 21 02 // Standby
            // TG_LSB
            printh 00 // Reserved
            // TG_MSB
            printh 00 // Reserved
            // VAL (4 bytes to be packed into 5 groups of 7 bit)
            // Seconds til standby, 1-3600
            sys0=thsp
            sys2=sys0
            sys2&=0x7f
            prints sys2,1
            sys0>>=7
            sys2=sys0
            sys2&=0x7f
            prints sys2,1
            // Standby uses less than 14 bits, hardcode remaining bytes.
            printh 00 00 00
            // SYSEX_END
            printh f7
            //
            // Button Hold Time
            // SYSEX_START DMID VERSION DEVICE
            printh f0 00 26 05 01 7f
            // PN_LSB PN_MSB
            printh 22 02 // Button Hold Time
            // TG_LSB
            printh 00 // Reserved
            // TG_MSB
            printh 00 // Reserved
            // VAL (4 bytes to be packed into 5 groups of 7 bit)
            // Time in ms, 50-9999
            sys0=nHoldTime.val
            sys2=sys0
            sys2&=0x7f
            prints sys2,1
            sys0>>=7
            sys2=sys0
            sys2&=0x7f
            prints sys2,1
            // Standby uses less than 14 bits, hardcode remaining bytes.
            printh 00 00 00
            // SYSEX_END
            printh f7
            //
            // Background Shutdown
            // SYSEX_START DMID VERSION DEVICE
            printh f0 00 26 05 01 7f
            // PN_LSB PN_MSB
            printh 23 02 // Background Shutdown
            // TG_LSB
            printh 00 // Reserved
            // TG_MSB
            printh 00 // Reserved
            // VAL (4 bytes to be packed into 5 groups of 7 bit)
            // Bitfield. Bit 0: enable/disable background shutdown
            prints nBackOff.val,1
            // Bitfield uses less than 7 bits, hardcode remaining bytes.
            printh 00 00 00 00
            // SYSEX_END
            printh f7
            //
            // Dark Mode
            // SYSEX_START DMID VERSION DEVICE
            printh f0 00 26 05 01 7f
            // PN_LSB PN_MSB
            printh 24 02 // Background Shutdown
            // TG_LSB
            printh 00 // Reserved
            // TG_MSB
            printh 00 // Reserved
            // VAL (4 bytes to be packed into 5 groups of 7 bit)
            // 0: light mode, 1: dark mode
            prints btDark.val,1
            // Value uses less than 7 bits, hardcode remaining bytes.
            printh 00 00 00 00
            // SYSEX_END
            printh f7
            //
            // Settings applied, current state is the new "original" state
            originalState.val=crcval
        
Hotspot fCRC
    Attributes
        ID               : 46
        Scope            : local
        Send Component ID: disabled
    
    Events
        Touch Press Event
            // Calculate CRC over all settings on the page.
            crcrest 1,0xFFFF
            crcputs nHoldTime.val,4
            crcputs dim,1
            crcputs thsp,1
            crcputs nBackOff.val,4
            crcputs btDark.val,1
        
Hotspot fLoadColors
    Attributes
        ID               : 47
        Scope            : local
        Send Component ID: disabled
    
    Events
        Touch Press Event
            // Changes all page components according to the current color set.
            // Note: This component has to be the last component of the page.
            //
            // sys0: component id
            // sys1: component type
            // sys2: picture id offset for current color mode
            sys2=Settings.colorMode.val*Settings.picCount.val
            for(sys0=0;sys0<fLoadColors.id;sys0++)
            {
                // More convenient for typing
                sys1=b[sys0].type
                if(sys1==121)
                {
                    // Types that have bco
                    // page
                    if(b[sys0].bco==Settings.backCol2Deflt.val)
                    {
                        b[sys0].bco=Settings.backCol2.val
                    }else
                    {
                        b[sys0].bco=Settings.backCol.val
                    }
                }else if(sys1==54||sys1==59||sys1==116||sys1==55)
                {
                    // Types that have bco, pco, and sta:
                    // number, float, text, scroll text
                    if(b[sys0].sta==1)
                    {
                        if(b[sys0].bco==Settings.backCol2Deflt.val)
                        {
                            b[sys0].bco=Settings.backCol2.val
                            b[sys0].pco=Settings.frontCol2.val
                        }else
                        {
                            b[sys0].bco=Settings.backCol.val
                            b[sys0].pco=Settings.frontCol.val
                        }
                    }
                }else if(sys1==98||sys1==53)
                {
                    // Types that have pco, pic, pco2, pic2, sta:
                    // button, dual-state button
                    if(b[sys0].sta==2)
                    {
                        b[sys0].pco=Settings.frontCol.val
                        b[sys0].pco2=Settings.backCol.val
                        b[sys0].pic=b[sys0].pic%Settings.picCount.val
                        b[sys0].pic+=sys2
                        b[sys0].pic2=b[sys0].pic+1
                    }
                }else if(sys1==58)
                {
                    // Types that have bco, pco
                    // QR Code
                    b[sys0].bco=Settings.backCol.val
                    b[sys0].pco=Settings.frontCol.val
                }else if(sys1==1)
                {
                    // Types that have pic, pic1, pic2:
                    // slider
                    b[sys0].pic=b[sys0].pic%Settings.picCount.val
                    b[sys0].pic+=sys2
                    b[sys0].pic1=b[sys0].pic
                    b[sys0].pic2=b[sys0].pic2%Settings.picCount.val
                    b[sys0].pic2+=sys2
                }
            }
        
Hotspot hHelp
    Attributes
        ID               : 48
        Scope            : local
        Send Component ID: disabled
    
    Events
        Touch Press Event
            // Determine component/feature that would have been touched.
            sys1=0
            for(sys0=fLoadColors.id;sys0>=0;sys0--)
            {
                // Ignore hotspots, touchcaps, variables
                if(b[sys0].type!=5&&b[sys0].type!=51&&b[sys0].type!=52&&b[sys0].type!=109)
                {
                    x0=b[sys0].x
                    y0=b[sys0].y
                    x1=b[sys0].w
                    y1=b[sys0].h
                    x1+=x0
                    y1+=y0
                    if(tch0>=x0&&tch0<x1&&tch1>=y0&&tch1<y1)
                    {
                        sys1=sys0
                        // abort loop
                        sys0=-1
                    }
                }
            }
            if(currentHelp.val>=0&&sys1==bReturn.id)
            {
                // Return button has been pressed while help is being displayed. This means
                // hide the help text again (see touch release event)
                bReturn.val=1
            }else if(sys1==btHelp.id)
            {
                // Question mark button has been pressed. Disable help mode (see touch release event).
                btHelp.val=0
            }else if(currentHelp.val>=0)
            {
                // Help is being displayed and something else has been pressed.
                // Act as if the page background had been pressed.
                // Note: this can make other UI elements to "pop up", therefore bring the text back on top
                // TODO: Prevent flickering!
                click 0,1
                doevents
                ref tHelp
            }else
            {
                // Show help according to what has been touched.
                // Assume that some new help will be displayed
                sys0=1
                tHelp.txt=""
                if(Settings.firstHelp.val!=0)
                {
                    Settings.firstHelp.val=0
                    tHelp.txt+="Help Mode Enabled \r\r"
                    tHelp.txt+="You've enabled the on-screen help by pressing the question mark at the top right \r"
                    tHelp.txt+="corner. As long as it's active, you can press any part of the UI and get a description \r"
                    tHelp.txt+="of what that button/slider/... does. \r"
                    tHelp.txt+="Press the X button at the top left to get help on another part of the UI. \r"
                    tHelp.txt+="Press the question mark at the top right to leave help mode and resume normal\r"
                    tHelp.txt+="operation. \r"
                    tHelp.txt+="Press any other part of the screen, including this description, to disable all outputs. \r"
                    tHelp.txt+="For more information, check the help on the page background.\r"
                    tHelp.txt+=" \r"
                    tHelp.txt+="This tip won't reappear until you reset or power cycle Syntherrupter. \r"
                }else if(sys1==tTitle.id)
                {
                    tHelp.txt+="General Settings \r\r"
                    tHelp.txt+="It's called 'general', but this page actually contains all the settings related to the UI. \r"
                }else if(sys1==tUser.id)
                {
                    tHelp.txt+="Current User \r\r"
                    tHelp.txt+="The name of the currently active user. This determines the range within which you \r"
                    tHelp.txt+="can operate Syntherrupter. Go to the main menu to change the current user. \r"
                }else if(sys1==tMSI.id||sys1==tMML.id||sys1==tMLS.id)
                {
                    tHelp.txt+="Active Modes \r\r"
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

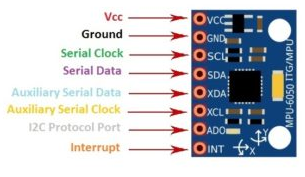
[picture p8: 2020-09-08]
Documentation/Wiring and Schematics/MPU-6050 Pinout.png

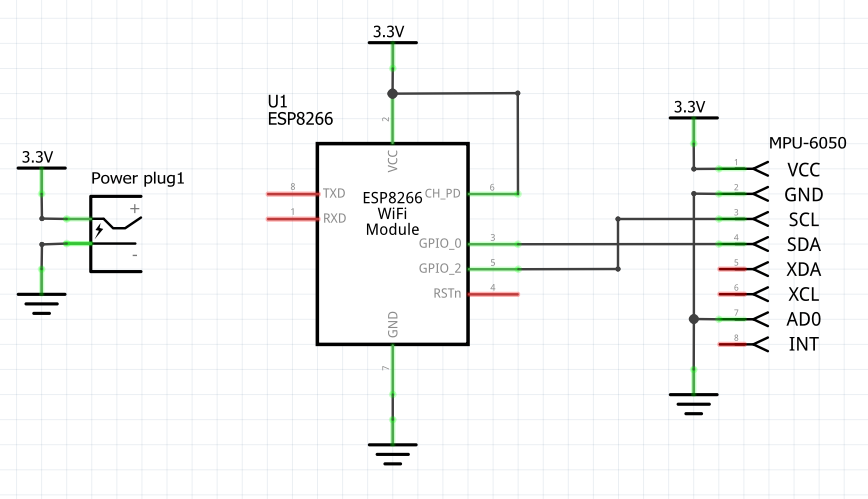
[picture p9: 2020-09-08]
Documentation/Wiring and Schematics/Lightsaber Sender/Lightsaber Sender Schematic.png

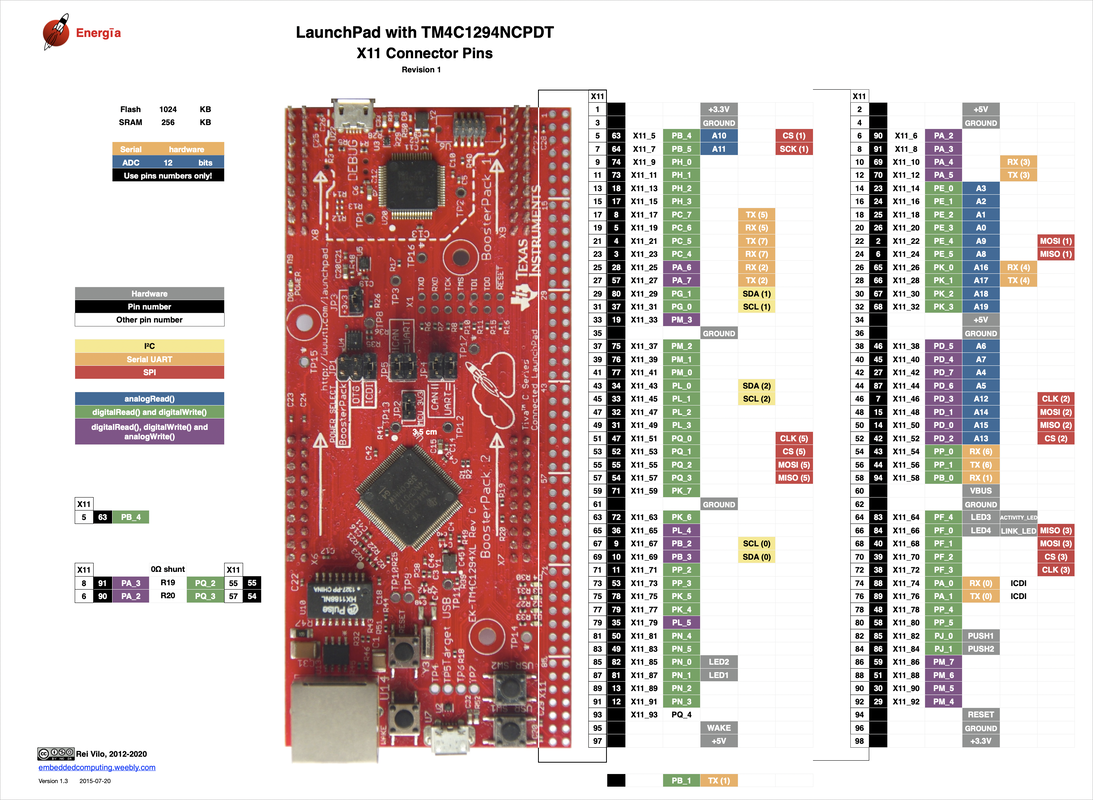
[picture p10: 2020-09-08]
Documentation/Wiring and Schematics/TM4C1294XL Pinout 2.png

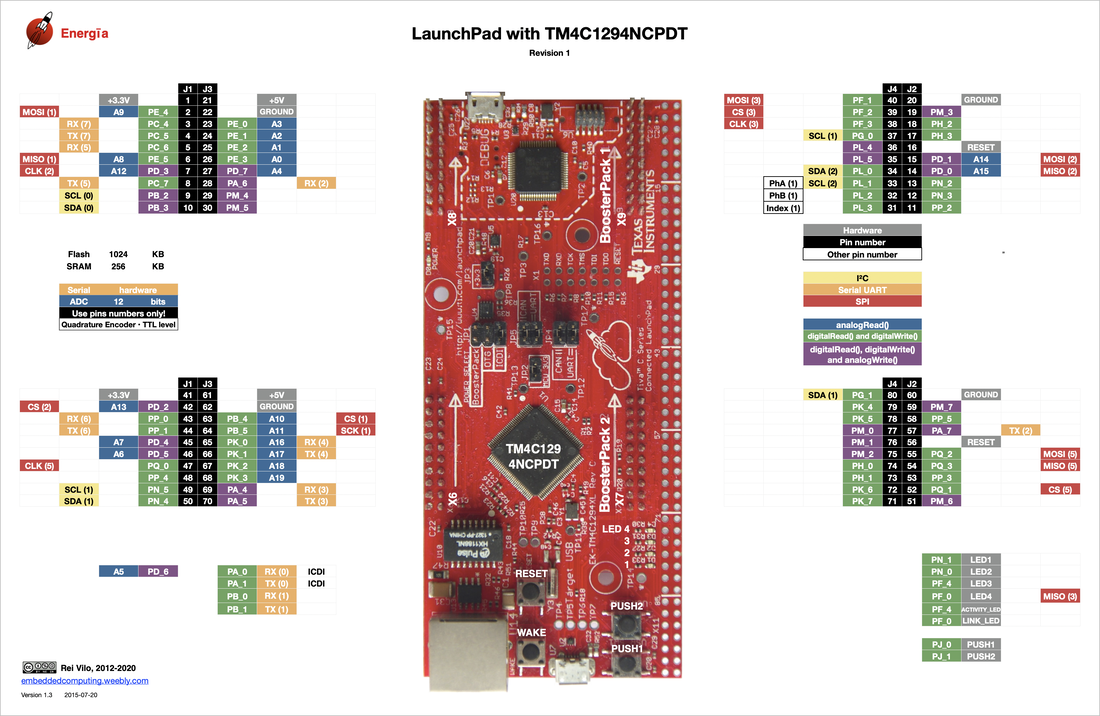
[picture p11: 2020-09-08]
Documentation/Wiring and Schematics/TM4C1294XL Pinout 1.png

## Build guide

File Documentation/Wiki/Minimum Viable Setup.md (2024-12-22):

# Minimum Viable Setup

[Back to the Getting Started Guide](Getting%20Started.md#readme)

The minimum viable setup is the bare minimum you need to even run the Syntherrupter firmware. It won't be ready to use yet but it will allow you to flash firmwares and get to know the user interface. 

## Index

* [Index](#index)
* [Firmware](#firmware)
* [Tiva Microcontroller](#tiva-microcontroller)
* [Display](#display)
	* [Introduction](#introduction)
	* [Suitable Models](#suitable-models)
	* [Without a Display](#without-a-display)
	* [Wiring](#wiring)

## Firmware

You'll always need a Syntherrupter firmware, preferrably the latest release. You find all releases here: https://github.com/MMMZZZZ/Syntherrupter/releases/

Read the release notes and download the attached ZIP file. It includes all the firmware binaries you'll need. 

Details about how to flash those firmwares are described on a separate page: [Firmware Flashing](Firmware%20Flashing.md#readme). 

## Tiva Microcontroller
The heart of Syntherrupter is the TM4C1294XL LaunchPad from TI. The Microcontroller is part of their *Tiva* family (Cortex M4F microcontrollers), hence I'll call it *Tiva* in the following.

This dev board can be bought [directly from Texas Instruments](https://www.ti.com/tool/EK-TM4C1294XL#order-start-development) for 20$, or from distributors like Mouser.

Everything else will connect to this board. How? Where? What pins? Beside the information given here you should check the *[Wiring and Schematics](/Documentation/Wiring%20and%20Schematics)* folder which includes schematics and pinouts. 

## Display

### Introduction

Syntherrupter was originally designed as touch screen device. However, if you don't want a graphical user interface you can easily control it [via command line](https://github.com/MMMZZZZ/Syfoh#readme), too. In that case you really only need the Tiva board.

Syntherrupters UI is designed for a special touch display called "Nextion". They have their own microcontroller that runs the whole UI which makes development *a lot* easier. Assembly gets easier, too. No 40 pin flat-flex cable, only 5V supply and two data pins. 

There are multiple display versions that can do the job. If you don't care and simply want to go with the recommended display from the recommended shop, click [here](https://www.itead.cc/5-0-nextion-intelligent-series-hmi-resistive-capacitive-touch-display-without-enclosure.html) and you're good.

Btw. since they are resistive touch screens, they aren't affected by EMI like the capacitive screen of your smartpone. 

You don't need a standalone interrupter? Well, you can run the user interface on the PC, too. In that case you don't need a display at all ([see below](#without-a-display)).

### Suitable Models
Nextions ease of use comes at a cost. Literally. These displays are rather expensive, starting at 64$ for the 5" version. Starting? Yes, there are actually 6 displays that are suitable for Syntherrupter:

* `NX8048T050_011R`: Nextion 5" Basic series ([Official shop: 65$](https://www.itead.cc/nextion-nx8048t050.html))
* `NX8048T070_011R`: Nextion 7" Basic series ([Official shop: 75$](https://www.itead.cc/nextion-nx8048t070.html))
* `NX8048K050_011R`: Nextion 5" Enhanced series ([Official shop: 72$](https://www.itead.cc/nextion-nx8048k050.html))
* `NX8048K070_011R`: Nextion 7" Enhanced series ([Official shop: 83$](https://www.itead.cc/nextion-nx8048k070.html))
* `NX8048P050_011R`: Nextion 5" Intelligent series ([Official shop: 64$](https://www.itead.cc/5-0-nextion-intelligent-series-hmi-resistive-capacitive-touch-display-without-enclosure.html))
* `NX8048P070_011R`: Nextion 7" Intelligent series ([Official shop: 73$](https://www.itead.cc/nextion-nx8048p070-011r-011c.html))

I recommend buying them from the official shop, but some of them are available from Mouser, Digikey, etc. 

The R at the end is important! It indicates that its the version with *resistive* touch. There are also versions with *capacitive* touch, marked by a `C` and versions with *no touch*, marked with an `N`. 

The three different series differ by quite some features but the only important difference for Syntherrupter is the processor speed. The Basic series runs at 48MHz, the Enhanced one at 108MHz and the Intelligent one at 200MHz. The latter one used to be more expensive than the other two (which somewhat makes sense) but right now it's not. So by all means, go for it. Makes the UI run much smoother than a basic series screen. 

Plot twist: Nextion is actually not much more than a rebranding. The displays originally come from the chinese manufacturer TJC. Buying directly from those is 30-50% cheaper but they only sell within China so you have to use an import service like Superbuy. Still cheaper than buying a Nextion but also slower. 

The TJC displays have almost the same model numbers and start with `TJC` instead of `NX`:

* `TJC8048T050_011R`: TJC 5" T0 (Basic) series
* `TJC8048T070_011R`: TJC 7" T0 (Basic) series
* `TJC8048K050_011R`: TJC 5" K0 (Enhanced) series
* `TJC8048K070_011R`: TJC 7" K0 (Enhanced) series
* `TJC8048X350_011R`: TJC 5" X3 (Intelligent) series (slower flash)
* `TJC8048X370_011R`: TJC 7" X3 (Intelligent) series (slower flash)
* `TJC8048X550_011R`: TJC 5" X5 (Intelligent) series
* `TJC8048X570_011R`: TJC 7" X5 (Intelligent) series

To keep things simple I won't write "Nextion or TJC display" every time but simply call it "Nextion". 

**Warning!** You can find the displays on ebay, too. However, in most cases you'll get a TJC display even though it says Nextion. For Syntherrupter this doesn't make a difference but if you ever want to do something with them on your own, be careful about this or you will run into problems. 

### Without a display

The user interface can be run on a Windows PC. Unlike the command line interface the GUI requires an additional Serial to USB converter that connects to the same Pins as the Nextion display would ([see below](#wiring)). 

* Download, install and open the Nextion Editor. 
  * For firmwares up to v4.1.3 you need Nextion Editor v1.61.1 (Download as [ZIP (portable)](https://nextion.tech/download/nextion-setup-v1-61-1.zip) or [Installer](https://nextion.tech/download/nextion-setup-v1-61-1.exe)). 
  * For firmware versions 4.1.4 to 4.2.0-beta.5 you need Nextion Editor v1.62.1 which is not available for download anymore; Nextion wants to force people to use v1.63.x and newer. For the record, here are the broken links: [ZIP (portable)](https://nextion.tech/download/nextion-setup-v1-62-1.zip), [Installer](https://nextion.tech/download/nextion-setup-v1-62-1.exe). Workaround: download the "Source Code" zip file attached to the release and open the .HMI file that can be found in the extraced zip content under `Syntherrupter_Nextion/Syntherrupter_Nextion.HMI`. You can use pretty much any Nextion editor version but I'd recommend v1.63.3 (see next point). Once you opened the file in the editor, contine with the steps below. 
  * For firmware versions 4.2.0-beta.6 and newer you need Nextion editor v1.63.3 (Download as [ZIP (portable)](https://nextion.tech/download/nextion-setup-v1-63-3.zip) or [Installer](https://nextion.tech/download/nextion-setup-v1-63-3.exe)). 
* Click "Debug" on the top right. A file dialog opens. Select the *Syntherrupter_Nextion_NX8048T050.tft* file from the release zip file. 
* A new window opens. At the bottom left select "User MCU Input" and then the COM port of the Serial to USB converter. Baud rate is 115200baud/s.
* You may need to reset the Tiva. 
* You should see the Syntherrupter logo. Since its a touch screen firmware, you can only use your mouse; no keyboard. 

### Wiring

Tiva pins:
* PA4 connects to Nextions TX pin (blue)
* PA5 connects to Nextions RX pin (yellow)

Both Tiva pins are 3.3V logic pins, capable of 2mA current. They are 5V tolerant.

The Nextion display requires regulated 5V at 1A. If possible you should not power the display through the Tiva LaunchPad. The PWM modulated backlight causes a rather strong ripple that may cause issues. If you're facing weird behavior you can try adding a low ESR capacitor in the ballpark of 220uF across the DC input jack on the Nextion screen itself. This greatly reduces the PWM ripple.

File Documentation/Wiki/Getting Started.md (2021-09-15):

# Getting Started with Syntherrupter

[Back to the wiki main page](README.md#readme)

So you want to build your own Syntherrupter? Great! This page will guide you. First you'll learn about what you need to build one, then how you get it ready to use, and finally we'll take a quick tour through the user interface. 

## Index
* [Index](#index)
* [Hardware](#hardware)
	* [Minimum Viable Setup](#minimum-viable-setup)
	* [Options](#options)
* [Firmware](#firmware)
* [User Interface](#user-interface)
	* [First Start](#first-start)
	* [Login Page](#login-page)
	* [Main Menu](#main-menu)
	* [Simple Mode](#simple-mode)
	* [MIDI Live Mode and Lightsaber Mode](#midi-live-mode-and-lightsaber-mode)
	* [Settings](#settings)
* [Done!](#done)

## Hardware

There's no finished PCB which you could buy and populate. Since Syntherrupter is based on a dev board many things can be connected via jumper wires. However, depending on which features you want to include, you'll probably want to use a breadboard PCB or design your own PCB. 

### Minimum Viable Setup

No matter what features you want to (not) have this is what you'll always need. The minimum viable setup doesn't require any soldering or additional components. 

Link to the page: [Minimum Viable Setup](Minimum%20Viable%20Setup.md#readme)

### Options

Once you have the minimum viable setup, you can extend it by any combination of the following options. Each option is described on its own page.

* [Optical transmitters for up to 6 independant coils](HW/Optical%20Outputs.md#readme)
* Shielded encasing
* Powerbank for standalone operation
* [MIDI Input jack](HW/MIDI%20Input.md#readme)
* [Lightsabers](HW/Lightsaber%20Receiver.md#readme)

## Firmware

Once the hardware is done, you can flash the Syntherrupter firmware. Step-by-step guide over here: [Firmware Flashing](Firmware%20Flashing.md#readme). 

*Note: actually, you could already flash the firmware once you have the minimum viable setup, but I assume most people want to get the hardware finished before messing with software.*

## User Interface

Firmwares flashed? Then let's get this party started!

### First Start
The first time Syntherrupter is powered up, you'll see a warning. Since nobody ever used this thing, its EEPROM is still empty and contains no valid settings. This warning will stay until you actually open and close the settings. 

Let's ignore this warning for a second and take a look at the UI first. Note that at this point all safety limits are at 0. This means you won't get any output signals until you change them in the settings. We'll get to that later.

Hit any part of the screen to continue. 

### Login Page

Syntherrupter supports three different users with different rights. By default you'll automatically log in as "Master Yoda", the user with all rights (think of it as the "Admin" or "root user"). We'll get to Syntherrupters User Management a bit later.

### Main Menu

*Complete documentation of the main menu: [Main Menu](UI/Menu.md#readme)*

The Main Menu links everything together. It's the "root" of the user interface. 

It contains 6 buttons. 
* At the top you have the three modes of operation of Syntherrupter: Simple, MIDI Live and Lightsaber. Click on them to bring up the controls for that mode. 
* Then we have Help and Info. You should check it out if you're new and still need to look up many things in the wiki. 
* Next one in the row is Settings. This is where you configure things like Username/password, screen brightness, safety limits and many other things. 
* Last one is Switch User at the bottom. It brings you back to the login page. At this point I should probably tell you, that the auto login password is `0`. 

### Simple Mode

*Complete documentation of the Simple Mode: [Simple Mode](UI/Simple.md#readme)*

Let's check Simple mode first. This is a good place to learn about some basic usage concepts of Syntherrupter. 

#### The Sliders

The page contains three sliders, for ontime, BPS/frequency and duty cycle. If you wonder why you need three, you're kinda right, three is redundant. This has two reasons: sometimes you want to control the "power" via the ontime, and sometimes by the duty cycle. The second reason is that no matter how you like to control the signal, you probably always want to know both values. First lesson: 

When you play with the sliders, you'll see that all values update automatically. If you increase the ontime, the duty increases, too. Where it gets interesting is when you change the BPS. Should it keep the ontime or keep the duty setting? Answer: It keeps whatever you edited last. Try it out, change the ontime, then the BPS. Now set the duty cycle and change the BPS again. 

#### Selecting the outputs

If you have more than one output, you'll a button for each output below the sliders. An "empty" button means that this output will not be affected by the next change you make. A "filled" button on the other hand means this output *will* be set to whatever you enter with the sliders.

Under each button you'll find what values are currently active on this output. Imagine you have six coils and you set each coil to different values - you wouldn't remember the values of the first one when you're done with the last one. Okay let's be fair, maybe you would but I wouldn't for sure.

Note that for now the ontime stays at zero because the coil limits don't allow any higher value yet. As I said we'll check this later. 

#### Apply manually or automatically

Now that you know *where* your settings will be applied, let's talk about *when* this happens

At the bottom you'll see a button that says *On Release*. This is when the values you enter will be applied. The moment you release any of the three sliders at the top, the settings will be applied to all the outputs you have currently selected. 

If you press that *On Release* button, it will change to *Manually* and another button appears: *Apply Now*. Now you can make as many changes to the sliders you want. Only when you click the *Apply Now* button they'll affect the outputs. Useful if you want to change f.ex. both ontime and BPS. 

Pressing the *Manually* button "again" and it changes to *Immediately*. This means that the outputs will already update while you move the sliders. 

#### Emergency stop

**Important**: If your coil is burning, cut the power and/or unplug the fibre cables. Don't rely on any software features.

Assuming a less urgent emergency (whatever that means), hit the empty background, f.ex. right of the return button. You'll see that all outputs jump to zero ontime and zero duty. 

Change at least one output back to anything non-zero and press the title. The same thing happens. 

To sum up: anything that's not a button, not a slider and in general not interactive will disable the outputs. This works on all pages. 

#### Running Modes in Parallel

By now you know pretty much all there's to know for the Simple mode. Let's return to the main menu. But wait - what's that? Why does that return button have a double outline?

A double outline indicates that the button has not only a "normal" function (f.ex. returning to the main menu) but an additional function when you keep it pressed. 

In the case of the return button a simple push stops Simple mode and brings you back to the main menu. If you keep it pressed, it will still bring you back to the main menu, but simple mode will continue to run in the background. Admitted this feature makes not a lot of sense for Simple mode, but it does make a ton of sense for MIDI Live mode and Lightsaber mode.

If you look at the bottom right, you'll see the three modes listed. They indicate what mode is currently active. When you entered Simple mode the according field got highlighted. If you keep the return button pressed, you'll see that it stays highlighted even though you're back to the main menu. 

At this point you may think again about the emergency stop. Imagine how much time it would take to cycle through all modes and stop each one of them. The emergency stop disables the outputs entirely, no matter what mode is active. 

### MIDI Live Mode and Lightsaber Mode

They follow the same principles as Simple Mode. Since this is only the Getting Started guide, I recommend you to check the according wiki pages: [MIDI Live Mode](UI/MIDI%20Live.md#readme), [Lightsaber Mode](UI/Lightsaber.md#readme).

### Settings

*Complete documentation of the Settings: [Settings](UI/Settings.md#readme)*

Let's leave the operation modes for now and look at the settings. 

There are 6 settings pages:
* General
* Envelope
* Users
* Coil Limits
* Nextion<->USB
* ESP<->USB

#### Coil Limits

*Complete documentation of the Coil Limits: [Coil Limits](UI/Coil%20Limits.md#readme)*

Let's look at the Coil Limits because they cover the most important safety feature of Syntherrupter. These settings apply equally to all modes. In fact, all modes sit on top of what I call the "Core" of Syntherrupter. That's the code that actually generates all the output signals. Each mode can add tones to any outputs. The Core then checks all tones of all modes together against all the limits and generates an output signal that exceeds none of them. 

The following limits can be set:
* *max. Ontime* (0us-41ms) specifies what's the longest ontime. 
* *min Offtime* (0us-1270us) specifies the minimum time between two succeeding ontimes. This is necessary because the primary current needs time to drop back to zero after an ontime. Since all tesla coil drivers I'm aware of assume the primary current to be zero at the beginning of the ontime, a too small min. Offtime would lead to hardswitching. 
* *max. Duty* (0%-51%) highest duty cycle of the output signal. This is mainly useful to prevent any components from overheating. It is calculated by adding the duty cycle of every single tone. 
* *max. MIDI Voices* (1-16) limits the number of simultaneous voices in MIDI Live mode. This does not affect the other modes when running multiple modes in parallel. If you set the limit to 6, you will not hear more than 4 simultaneous notes in your MIDI playback. However you can still have 4 Lightsabers playing in addition to the 6 MIDI voices on the same output. The reason for the limit affecting only the MIDI Live mode is that you can easily control the number of lightsabers that play. No need somehow limit that. 

You can modify any of the values by tipping on it and typing a new value using the keypad at the bottom right. The settings will be applied when you hit the return button. 

#### User Settings

*Complete documentation of the User Settings: [User Settings](UI/Users.md#readme)*

I'll quickly talk about this one because there're a few pitfalls.

Similar to the Coil Limit page you get a table with the different settings for each user. The leftmost user has the least rights, the rightmost user is the "Admin"/"root user". 

First pitfall, if you want to change the user passwords, remember that on the login screen you only have a keypad! Don't enter anything else than digits! Password length can be anything from 1-16. 

Out of the box the Admin password is `0`. This specific password tells Syntherrupter to log in automatically into this account. Of course, you can change this password and/or set the password of another user to `0`, which causes Syntherrupter to auto login into that account. 

Next pitfall are the user limits. They are independant of the coil limits and they only affect the ranges of the sliders. F.ex. if the user duty limit is set to 5% you can't set the per-note duty higher than 5%. However, you can still get a 10% output signal when playing multiple notes simultaneously. This of course assumes that your coil limits allow such a signal. 

Before you're getting crazy, no you can't edit the ontime and duty settings of the "Admin". They are automatically set to the highest of your coil limits. By definition the Admin has full rights, hence a lower value makes no sense. And by definition of the coi limits a higher value makes no sense either. 

#### Applying and Storing

Most settings are applied when leaving the according settings page. However at this point they're not yet written to the EEPROM (and thus remembered in case of a power cycle). This only happens when you return to the main menu. Hence that button says *Save* instead of *Return*. 

If you power cycle Syntherrupter now, you won't get the warning anymore. The EEPROM now contains a valid config. 

## Done!

You've learned the basics about Syntherrupter. There's a lot more to learn and unfortunately not everything is obvious. However, you know the most important concepts and should be able to explore many if Syntherrupters features on your own. 

Don't be afraid of playing around; remeber, the coil limits protect your coil from oopsies.

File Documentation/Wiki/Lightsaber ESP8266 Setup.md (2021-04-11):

# Lightsaber ESP8266 Setup

[Back to the wiki main page](README.md#readme)

The lightsabers use ESP8266s to communicate with the Syntherrupter. They are cheap and supposed to work even in a noisy environment like a tesla coil. 

This page covers how to get those ESP8266 (in the following: ESP) ready to work. This requires the circuitry described on the [Lightsaber Receiver](HW/Lightsaber%20Receiver.md#readme) wiki page. To build the lightsabers themselves, please have a look at the pictures [here](/Documentation/Wiring%20and%20Schematics/Lightsaber%20Sender).

The ESPs require their own firmware which has to be flashed once. Ideally they shouldn't require updates if there're new features, because they are not involved in the actual processing of the sensor data. This is completely handled by the Tiva microcontroller. 

## Index
* [Index](#index)
* [Flashing for Windows Users](#flashing-for-windows-users)
* [Flashing with cross-plattform tool](#flashing-with-cross-plattform-tool)
* [Lightsaber ID setting](#lightsaber-id-setting)
* [Transmitters, Receivers, Pairing](#transmitters-receivers-pairing)

## Flashing for Windows Users
For Windows exists a graphical tool for flashing the ESPs. 

*Some of the following steps and pictures are taken from [Allen Derushas how-to](https://github.com/aderusha/HASwitchPlate/blob/master/Documentation/01_Arduino_Sketch.md).*

### Requirements
* [Latest Syntherrupter release](https://github.com/MMMZZZZ/Syntherrupter/releases/)
* [NodeMCU Flasher](https://github.com/nodemcu/nodemcu-flasher/) ([32bit download](https://github.com/nodemcu/nodemcu-flasher/raw/master/Win32/Release/ESP8266Flasher.exe) / [64bit download](https://github.com/nodemcu/nodemcu-flasher/raw/master/Win64/Release/ESP8266Flasher.exe)). 

### Steps
* Extract the ESP firmware from the Syntherrupter release zip file. The file is called "Syntherrupter_Lightsaber.ino.generic.bin". 
* Connect Syntherrupter to your computer and choose *ESP<->USB* in Syntherrupters *Settings* menu. 
* Connect your ESP to Syntherrupter. Make sure that the ESP GPIO0 pin is connected to ground.
* Launch the NodeMCU flasher and select the COM port for your device from the *COM Port* drop-down menu
* Select the *Config* tab (1), then click the top-most gear icon to the right (2) to open a file browser. NodeMCU_Flasher_OpenFirmware 
* Switch back to the *Operation* tab and click *Flash(F)*.
* Disconnect the ESP from Syntherrupter, connect the next one, and click again on *Flash(F)*. Repeat for all ESPs.
* Once all ESPs are flashed, power cycle Syntherrupter to leave ESP<->USB Passthrough mode. 

## Flashing with cross-plattform tool
You have to use the Python command line tool from Espressiv. But don't worry, it's very easy. 1 command to install the tool, 1 command to upload the firmware.

### Requirements
* [Latest Syntherrupter release](https://github.com/MMMZZZZ/Syntherrupter/releases/)
* [Python](https://www.python.org/downloads/). Installation is pretty straight forward. Make sure to check the option "Add Python to PATH". 
* [esptool](https://github.com/espressif/esptool). Installation is again pretty easy. Simply run the following in your command line: `python -m pip install esptool`. It will install the tool and everything needed to run it. 

### Steps
* Extract the ESP firmware from the Syntherrupter release zip file. The file is called "Syntherrupter_Lightsaber.ino.generic.bin". 
* Connect Syntherrupter to your computer and chose *ESP<->USB* in Syntherrupters *Settings* menu. 
* Connect your ESP to Syntherrupter. Make sure that the ESP GPIO0 pin is connected to ground. 
* Open a command line, type `esptool.py write_flash 0x0 "PATH_TO_THE_EXTRACTED_BINARY"`. It will scan all serial ports until it finds an ESP and uploads the firmware. You can speed up the scan part by specifing the port. Example when connected to COM3: `esptool.py -p COM3 write_flash 0x0 "PATH_TO_THE_EXTRACTED_BINARY"`.
* Repeat the last two steps for all of your ESPs.
* Once all ESPs are flashed, power cycle Syntherrupter to leave ESP<->USB Passthrough mode. 

## Lightsaber ID setting
For the Syntherrupter and for you it is important to distinguish each lightsaber. Therefore you have to assign a unique ID to each one of them. By default they all have the ID 1. Two lightsabers with the same ID will be treated as one. Their sensor data will be mixed together and you can only turn both on and off at the same time. 

To set the ID, connect the ESP you want to use in the lightsaber to the Syntherrupter. Enter lightsaber mode and hold the ID you want to assign to this ESP. It will be stored immediately in the ESPs flash, meaning you can immediately disconnect the ESP from the Syntherrupter after holding the button. And you only need to do this once for each lightsaber. 

While you can set an ID for the receiving ESP that will stay connected to the Syntherrupter, it is not important. The ID is only used by those ESPs which act as transmitter (see below).

## Transmitters, Receivers, Pairing
You might wonder how to configure an ESP for being a transmitter sitting in a lightsaber or the receiver connected to the Syntherrupter. Simple answer: you don't. Since only the ESPs in the lightsabers are actually connected to a MPU-6050 sensor they can recognize themselves what their role is. If a MPU-6050 is detected, the ESP will wait for the receiving ESP to power up and connect to it. 

Usually the pairing happens within seconds after power up. A successfull connection is visible by the blue LED on the ESPs lighting up. Sometimes the MPU-6050 fails to initialize and thus the ESP thinks he is a receiver, not a transmitter. In this case a power cycle usually solves the problem. 

Even more rare: for some unknown reason the receiving ESP sometimes stops working. Haven't found the reason yet. Again, a power cycle should solve the issue. 

Other than that pairing happens automatically. If the connection is lost, it should reestablish in less than a second. In my tests the connection was pretty solid, with only minor hickups every couple minutes. However that was without tesla coil...

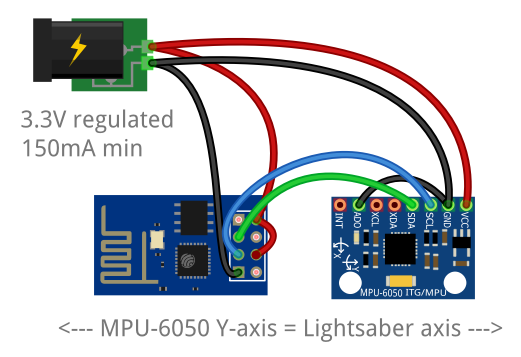
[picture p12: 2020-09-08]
Documentation/Wiring and Schematics/Lightsaber Sender/Lightsaber Sender Wiring.png

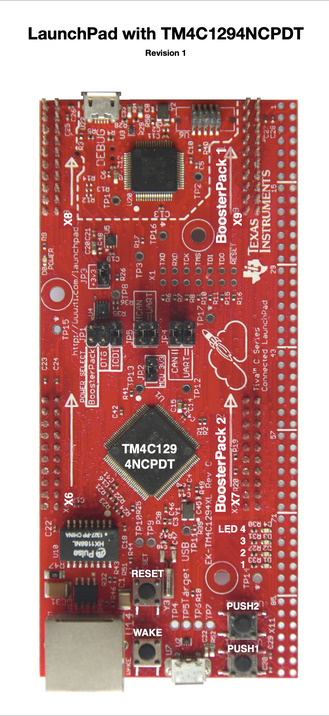
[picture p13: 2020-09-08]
Documentation/Wiring and Schematics/Syntherrupter Complete/TM4C1294XL.png

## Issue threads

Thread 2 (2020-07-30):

Editable ADSR Parameters

MMMZZZZ, 2020-07-30:
## Description
Currently ADSR parameters are set at compile time. They should rather be customizable at runtime, by the user.

## Tasks
- [x] Create GUI page which allows editing the parameter
- [x] Define communication protocol
- [x] Modify Tiva Firmware to receive and store changes.

## Related issues
*TBD*

Closed 2020-11-04.

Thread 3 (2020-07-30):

MIDI Commands for all Syntherrupter Settings

MMMZZZZ, 2020-07-30:
## Description
Just like the note to stereo mapping is controlled by NRPs, all the other parameters should be modifiable by MIDI commands, too. This would allow to embed the settings in your MIDI files so that you can switch between files without the need to change anything by hand (like stereo reaches).

## Tasks
- [x] Define MIDI SysEx and/or NRP commands for all settings
- [x] Add command processing to MIDI class
- [x] Send values to Nextion
- [x] Add option to send all current settings to the host.

## Related issues
*TBD*

MMMZZZZ, 2021-10-05:
Fully implemented with v4.2.0-beta.7

Closed 2021-10-05.

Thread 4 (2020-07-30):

Logarithmic Volume

MMMZZZZ, 2020-07-30:
## Description
Currently the MIDI velocity, volume, etc affect the resulting volume linearly. However, following the MIDI standard, they should be seen as logarithmic.

## Tasks
- [ ] Find out where exactly the exp function should be applied (at the end, intermediate, ...)
- [ ] Put it there.

## Related issues
*TBD*

MMMZZZZ, 2020-10-14:
If only I had read what standards and conventions *actually* say. The controller values are indeed linear, so everything is fine the way it is.

https://sound.stackexchange.com/questions/41549/is-midi-volume-scale-logarithmic

Closed 2020-10-14.

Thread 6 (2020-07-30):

More MIDI Program Settings

MMMZZZZ, 2020-07-30:
## Description
Currently there are 8 ADSR parameters for each MIDI program: 4 pairs of amplitude and duration values. However, there are more parameters that could change depending on the program and thus the desired sound. One example would be if the interpolation between two data points should be linear or exponential.

## Tasks
- [x] Define MIDI Program standard, incl. number of points, point properties, ... (current draft below)
- [x] Implement new functions in Tiva Firmware

## Related issues
*TBD*

Closed 2020-11-04.

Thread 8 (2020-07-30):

EEPROM Reset

MMMZZZZ, 2020-07-30:
## Description
Ok so you goofed up the passwords. What now? Wouldn't it be useful if you could set a jumper which makes the microcontroller reset all settings to default?
Just in case this really happened to you: If you're on v3.x.x: flash v2.0.1. If you're on v2.x.x: flash v3.0.0. After flashing the "new" version you may get a config warning on startup. That's fine! The config stored in EEPROM is not valid for the "new" firmware which forces it to use the default values. To overwrite the current data in the EEPROM with the default settings, enter the settings page, modify any value and return to the main menu.

## Tasks
- [ ] Search a good pin to be shorted to ground or VCC.
- [ ] Add check of this pin to the startup and reset EEPROM if jumper is set.

## Related issues
*TBD*

MMMZZZZ, 2021-01-08:
https://github.com/MMMZZZZ/Syntherrupter/blob/dev/Documentation/Wiki/Password%20Reset.md

Closed 2021-01-08.

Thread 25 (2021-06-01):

NX8048K050_011R not working from V4.1.4 and above

ffl-la, 2021-06-01:
NX8048K050_011R stopped working from firmware version 4.1.4 and the above. Last known good Version is 4.1.3

Lg Alessio

MMMZZZZ, 2021-06-01:
Hi @ffl-la,

I don't own a NX8048K050 display, so I only have the Nextion debugger to check the binaries. With the corresponding editor version (1.62.1), the TFT file opens and runs fine.

As the [release notes](https://github.com/MMMZZZZ/Syntherrupter/releases/tag/v4.1.4) say, the upgraded Nextion bootloader is much more sensitive to power supply issues. If changing the power supply, changing/shortening the supply cables and adding additional capacitance to the display don't fix the issue, you should measure the 5V and the 3.3V rail directly on the Nextion PCB to verify that they don't have any drops. Especially the 3.3V must be absolutely stable. For reference, when I encountered this issue, I made a [detailed post](https://unofficialnextion.com/t/new-nextion-editor-1-62-1-is-available/1182/9) about it. If you're still unsure, just post a picture of the traces here.

If this doesn't fix your issues, it'd be very helpful to get some more details about how exactly the device fails.

Kind regards,
Max

ffl-la, 2021-06-02:
Hallo Max

Vielen Dank! Ich hatte den verdacht es liegt an der Versorgung, ich habe es
mal mit einer Powerbank versucht hat aber auch nicht funktioniert. Wenn ich
Zeit hab werde ich mal messen.

Lg
Alessio

Am Di., 1. Juni 2021 um 23:57 Uhr schrieb MMMZZZZ ***@***.***
>:

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

MMMZZZZ, 2021-08-23:
*Closed because of inactivity*

Closed 2021-08-23.

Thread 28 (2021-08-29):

Syntherrupter v4.2.0 beta3 - simple mode outputs not in sync at low Hz

MadsBarnkob, 2021-08-29:
https://www.youtube.com/watch?v=kB5LqUTlLgs

See video where it can be seen and heard, that not all 6 outputs run synchronously in simple mode. It seems like 1-3 is in sync, while 4 to 6 is being "scanned".

MMMZZZZ, 2021-08-30:
Noticed this recently, too. With the unbuffered outputs it could have been possible to fix it somehow but with each coil having independent buffers and timers I think it’s not possible to sync them.

The main reason for this is that the buffers are processed by interrupt service routines (ISR) which take a little less than 2us. Because of interrupt priorities this means that the ISR of the last of the six timers may be delayed by as much as 5*2us. This is causes all timers to drift with respect to each other and I have no possibility to compensate for it.

My only suggestion would be to drive all coils by the same output of Syntherrupter in such cases. Can’t remember your switch configuration but it might be possible for you.

Regards,
Max

Closed 2021-09-08.

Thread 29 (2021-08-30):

Nextion Startup Timeout

MMMZZZZ, 2021-08-30:
## Problem
If the connection between the Nextion screen and the Tiva microcontroller is for some reason broken, the Nextion screen remains dark - which doesn‘t give the user any clues about what‘s wrong.

## Fix
Add a timeout on the Nextion startup screen that after x seconds shows an info message (something like „no connection to the Tiva micro; check your wiring“).

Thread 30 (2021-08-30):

No Emergency Shutdown on Startup and Login Screens

MMMZZZZ, 2021-08-30:
## Problem

Before Sysex was a thing it was impossible to generate any output signals on the Startup and Login screens. Therefore they don‘t contain any code for the emergency shutdown feature (hit any „inactive“ part like the background or titles to disable all outputs).

However, with Sysex it *is* possible to generate signals at any point, and I found myself using Sysex a lot (and the touchscreen sometimes not at all). This essentially means I don‘t have the emergency shutdown anymore.

## Fix

Add the emergency shutdown to these pages, too.

MMMZZZZ, 2021-10-05:
Fixed with v4.2.0-beta.7

Closed 2021-10-05.

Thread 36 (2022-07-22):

Popping noises when playing more than one note

WayneSeng, 2022-07-22:
Whenever I try to play two notes at once, there is this popping noise that changes repetition depending on what two notes im playing. For some reason, octaves sound fine without any pops or weird noises. I am running the latest version `4.2.1`, which has been reflashed multiple times. My setup is the bare minimum, with the tiva connected to a usb hub, a uart to usb converter with nextion editor, and a IFE-96E optical transmitter. I have attached the recording of the tesla coil at low power below.
[Polyphony_Noise.zip](https://github.com/MMMZZZZ/Syntherrupter/files/9165274/Polyphony_Noise.zip)

MMMZZZZ, 2022-07-23:
Hi @WayneSeng

Glad to hear your issue wasn‘t caused by a bug! I assume you were just under the limit where arcs start to form such that occasionally ontimes close together would cause a single discharge with popping sound.
 I‘d ask you for the future to close the old issue and open a new one instead of editing it into something completely different. Main reason being that I don‘t get notified about your edit and may miss it or start hunting a bug that doesn‘t exist.

Now for the modulation wheel. There is no config option available right now that‘d do that. However, there is the pitch bend command. Usually, keyboards have a pitch bend and a modulation wheel, and both are supported by Syntherrupter. Also, I don‘t know of any „standard“ MIDI command that would allow for oscillating pitch (like the modulation command) so I wonder how common that is…
Long story short, if you want an oscillating pitch you need to do it on your PC, keyboard or whatever you‘re using. If your software supports such a feature, I‘m pretty sure it‘ll be done using the pitch bend command (and will thus work with Syntherrupter). If your software doesn‘t support it, one could rather easily write such a thing in python f.ex.

Kind regards,
Max

WayneSeng, 2022-07-28:
Thanks @MMMZZZZ I will keep that in mind. It was a bit late and driving me a bit crazy as to why this was happening and of course it was me the entire time, so I apologize about that.

I am aware of the pitch bend command, however my DAW(Ardour) doesn't have a way to easily automate pitch bend commands. So when I needed to add vibrato to some parts of a song, I had to manually drag my mouse and change the automation timeline for pitch bend. And... If there is a way to easily add automation that I don't know off, please try to point me in the right direction. Anyway, im likely wrong, but the modulation on a MIDI keyboard can be configured for tremolo or vibrato right? On Syntherrupter, adding CC 1(modulation) adds tremolo, but it shouldn't be too hard to implement vibrato as well?

I didn't think about writing something in Python. I may try to implement a virtual LFO that outputs pitch bend commands after lets say a keyboard shortcut. I then record this automation in Ardour.

Appreciate it,
Wayne

MMMZZZZ, 2022-08-02:
Hi @WayneSeng,

I did some reading about tremolo and MIDI and found surprisingly little information. tl;dr seems to be that it's done using pitch bend commands and that there're no channel controllers for it. So I'll likely implement it via [NRPNs](https://github.com/MMMZZZZ/Syntherrupter/blob/dev/Documentation/Wiki/Custom%20MIDI%20Commands.md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).

So far there's only one LFO which is only used for the modulation, meaning any channel that enables modulation will be in sync and at the same frequency as all others.
A simple tremolo implementation would use the same LFO, so same frequency (and phase) again. By your experience, would that be okay?

Kind regards,
Max

WayneSeng, 2022-08-04:
Thanks @MMMZZZZ.

I honestly don't have as much experience either. I also don't own a synthesizer, so im not exactly sure if you can configure the modulation wheel for tremelo or vibrato.

That would be ok, but maybe you can use a unused CC effect to control the LFO frequency and another for the depth. This can give a bit more control over the sound.

Thanks,
Wayne

MMMZZZZ, 2022-08-05:
Hello again @WayneSeng,

I think you slightly misunderstood me. The LFO _is_ controllable in frequency (via [SysEx parameter `0x68` or `0x69`](https://github.com/MMMZZZZ/Syntherrupter/blob/v4.2.1/Documentation/Wiki/Custom%20MIDI%20Commands.md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), corresponding to the [Syfoh](https://github.com/MMMZZZZ/Syfoh#readme) commands `midi-lfo-freq` and `midi-lfo-bpm`)

My main question was whether or not it is sufficient to have only one LFO (frequency) that controls the tremolo and modulation effect on all channels?
Note that the LFO amplitude would be kept separate for all channels/usage cases. It's only about the frequency; whether or not that can be the same controllable one for all or not.

Kind regards,
Max

WayneSeng, 2022-08-07:
Hi @MMMZZZZ

Im not very familiar with SysEx commands, but I will definitely check those out in the future.

Yes, it should be sufficient. In my MIDI instrument, I only used one frequency that controlled the modulation.

Thanks,
Wayne

MMMZZZZ, 2022-08-07:
Hi @WayneSeng,

First of all, sorry for confusing tremolo and vibrato. Also, I had in mind you wanted to control the pitch in addition to the modulation wheel, not _with_ the modulation wheel. However, I feel like the latter one should be configured on your MIDI keyboard and/or your DAW (meaning, you control what MIDI messages are generated by moving that wheel/button/slider, instead of making Syntherrupter interpret standardized MIDI messages in a different way)

Anyways, I found out that vibrato _is_ mentioned in revisions of the MIDI standard, though so far it's unclear to me how to properly implement it. Thus I decided that for now I won't touch this until I understand _how_. Nonetheless, I thought the feature request was a good idea so I came up with my own implementation.

Basically, you can control vibrato using a newly added non-registered parameter (NRPs _should_ be supported by most decent MIDI editors/DAWs/...). Setting a value X causes a pitch oscillation to the same point as a pitch bend of X would cause. F.ex. with default settings a pitch bend of +4096 causes the pitch to increase by +1 semitone. Setting a vibrato of +4096 will thus cause a pitch oscillation reaching +1 (and -1) semitone. So it's the exact same amplitude/scale. It is thus also controlled - like pitch bend - by the pitch bend range parameter (standardized parameter to define the pitch bend range. Defaults to -2..2).
As described previously, the frequency can be controlled by changing the LFO frequency (using Sysex). It defaults to 5Hz.

I currently don't have the hardware to do any testing but I thought you might want to try this anyways, therefore I attached the Tiva binaries with the changes (no new Nextion binaries required). Flash them as any firmware update if you want to try. **Keep in mind that it's untested!** I suggest trying with speakers/piezos connected to the output first before hooking it up to an actual tesla coil.

[Syntherrupter_Firmwares_v4.2.1-vibrato.1_TivaOnly.zip](https://github.com/MMMZZZZ/Syntherrupter/files/9276824/Syntherrupter_Firmwares_v4.2.1-vibrato.1_TivaOnly.zip)
Documentation of this new feature can be found here: [vibrato/Documentation/Wiki/Custom MIDI Commands.md](https://github.com/MMMZZZZ/Syntherrupter/blob/vibrato/Documentation/Wiki/Custom%20MIDI%20Commands.md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)

Kind regards,
Max

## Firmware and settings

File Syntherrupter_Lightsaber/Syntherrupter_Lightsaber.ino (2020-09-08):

/*
 * Code for transmitting data from an MPU-6050 IMU via WiFi.
 * 
 * If the code detects the IMU (GPIO0: SDA, GPIO2: SCL), it will act as slave 
 * and send the data. If it can't detect the IMU it will act as master, create
 * the WiFi AP and collect data from slaves. This means the same code can be 
 * flashed to both master and slave devices.
 *
 * Pairing (Master)
 *   * Master creates WiFi AP with credentials specified below. 
 *   * Master creates server on port specified below.
 *   * If a new device connects (assumed to be a slave) the master checks if 
 *     there's still space in the list of slaves and if so, adds it to the 
 *     list. Otherwise it sends 0x00 to the slave and it won't be added. 
 *   * Master waits for the slave to send it's ID. If this does not happen
 *     within 100ms, master sends 0x00 to the slave and removes it from the 
 *     the list. Otherwise master returns the ID to the slave. 
 * Pairing (Slave)
 *   * Slave waits for the WiFi AP to appear and connects.
 *   * Slave waits for the master server to come up and connects to it.
 *   * Slave immediately sends its ID (default: 1, can't be 0).
 *   * Slave waits for a response. If the response is not equal to its ID,
 *     slave will enter endless loop. User has to reset the slave for a new 
 *     try (preventing unecessary connection retries to the master).
 * 
 * (Slave) ID
 *   Each ESP8266 stores its ID in its EEPROM which it uses to identify its 
 *   data packets (see below). The ID defaults to 1 and can go up to 255. 
 * 
 * Slave data packets
 *   Data packets from the slave to the master look like this:
 *     * Byte  0:       Slave ID
 *     * Byte  1 -  4:  X-Acceleration in g,   float, little endian
 *     * Byte  5 -  8:  Y-Acceleration in g,   float, little endian
 *     * Byte  9 - 12:  Z-Acceleration in g,   float, little endian
 *     * Byte 13 - 16:  X-Angle Rate   in °/s, float, little endian
 *     * Byte 17 - 20:  Y-Angle Rate   in °/s, float, little endian
 *     * Byte 21 - 24:  Z-Angle Rate   in °/s, float, little endian
 *
 * Master data packets
 *   Master collects data from each slave. Once a complete packet from a slave
 *   has been received, it will be sent via the master's UART. This assures 
 *   that different slave packets won't be scrambled together. 
 * 
 * Serial configuration
 *   The code is listening to the serial port for commands. It does this if 
 *   it detected no IMU (operates as master) and if there are no clients. 
 *   This makes sure that the Serial port is not used for anything else.
 *   Command format is pretty simple: 1 address byte, 1 data byte, both must 
 *   not be 0.
 *   Configurable parameters: 
 *     * Address 1: Slave ID. It will be stored to the EEPROM. If the 
 *                  device operates as slave, it will be applied after a 
 *                  restart.
 *   After processing the command, the data byte is returned. A value of 0
 *   means the processing was not successful or the command was invalid. 
 *
 * Debugging
 *   This code is full of Serial.print commands. Since the code is assumed to
 *   work, they are commented out. To get debugging information, replace all
 *   occurences of "//Serial.print" with "Serial.print". Same thing for 
 *   turning it off again. Serial.print* is _only_ used for debugging.
 */


#include <TaskScheduler.h>
#include <TaskSchedulerDeclarations.h>
#include <TaskSchedulerSleepMethods.h>
#include <ESP8266WiFi.h>
#include <Wire.h>
#include <MPU6050_light.h>
#include <EEPROM.h>

#ifndef APSSID
#define APSSID "Syntherrupter"
#define APPSK  "ICanChange!IPromise!"
#endif
#define PORT     8888
#define MAX_CLIENTS 4
#define DATA_SIZE  24
#define DATA_PERIOD_MS 30
#define SAMPLE_PERIOD_MS 5
#define TIMEOUT_FACTOR  3

#define MPU_SDA_PIN 0 // GPIO0
#define MPU_SCL_PIN 2 // GPIO2
#define MPU_SIGNAL_PATH_RESET 0x68

WiFiServer masterServer(PORT);
WiFiClient masterClients[MAX_CLIENTS];
WiFiClient slaveClient;
IPAddress masterIP;
MPU6050 mpu(Wire);
bool serialCommandsEnabled = true;
bool slave = 0;
uint8_t slaveIDs[MAX_CLIENTS];
uint32_t masterClientsTimeout[MAX_CLIENTS];
float slaveData[6];

// Task callbacks
void slaveReadMPUCallback();
void slaveConnectToMasterServerCallback();
void slaveSendDataCallback();

// Tasks
Task slaveReadMPU(SAMPLE_PERIOD_MS, TASK_FOREVER, slaveReadMPUCallback);
Task slaveSendData(DATA_PERIOD_MS, TASK_FOREVER, slaveSendDataCallback);
Task slaveConnectToMasterServer(DATA_PERIOD_MS * TIMEOUT_FACTOR, TASK_FOREVER, slaveConnectToMasterServerCallback);

Scheduler scheduler;


void slaveReadMPUCallback()
{
  mpu.update();

  float newData[6];
  newData[0] = mpu.getAccX();
  newData[1] = mpu.getAccY();
  newData[2] = mpu.getAccZ();
  newData[3] = mpu.getGyroX();
  newData[4] = mpu.getGyroY();
  newData[5] = mpu.getGyroZ();

  for (uint32_t i = 0; i < 6; i++)
  {
    if (fabsf(newData[i]) > fabsf(slaveData[i]))
    {
      slaveData[i] = newData[i];
    }
  }
}

void slaveSendDataCallback()
{
  uint8_t* dataBytes = (uint8_t*) ((void*) slaveData);
  if (slaveClient.connected())
  {
    slaveClient.write(slaveIDs[0]);
    slaveClient.write(dataBytes, DATA_SIZE);
  }

  for (uint32_t i = 0; i < 6; i++)
  {
    slaveData[i] = 0;
  }
}

void slaveConnectToMasterServerCallback()
{
  if (!slaveClient.connected())
  {
    // Wait for the master TCP Server to appear and connect to it.
    //Serial.print("Waiting for Master Server to appear");
    while (slaveClient.connect(masterIP, PORT) != 1)
    {
      //Serial.print('.');
      delay(200);
    }
    //Serial.println("\r\nConnected!");
    //Serial.println("Sending ID");
    slaveClient.setNoDelay(true);
    slaveClient.write(slaveIDs[0]);
    while (!slaveClient.available());
    uint8_t data = slaveClient.read();
    if (data != slaveIDs[0])
    {
      while (42)
      {
          // nfg; there's no space left for us or the communication went wrong. 
          // Hence we won't do anything anymore (User has to reset for a new try).
          yield();
      }
    }
  }
}

void setup()
{
  EEPROM.begin(128);
  scheduler.init(); 
  Serial.begin(115200);

  // Check if EEPROM has been written. Otherwise overwrite with default values.
  if (EEPROM.read(0) != 42)
  {
    EEPROM.write(0, 42);
    EEPROM.write(1, 1);
    EEPROM.commit();
  }

  Wire.begin(MPU_SDA_PIN, MPU_SCL_PIN);
  // Reset MPU (MPU6050 Register Map page 41
  delay(100);
  mpu.writeMPU6050(MPU6050_PWR_MGMT_1, 0b10000000);
  delay(100);  
  mpu.writeMPU6050(MPU_SIGNAL_PATH_RESET, 0b00000111);
  delay(100);
  // Search for MPU 6050. Its WHO_AM_I 
  byte whoAmI = mpu.readMPU6050(MPU6050_WHO_AM_I);
  //Serial.print("MPU6050 Who Am I: ");
  //Serial.println(whoAmI);
  
  // Depending on the MPU variant the WHO AM I register must contain either the value 0x68 or 0x72
  if (whoAmI == 0x68 || whoAmI == 0x72)
  {
    // If an MPU6050 has been found this device operates as a slave (since master and slave run the same firmware)
    //Serial.println("Entering slave setup.");
    slave = true;
    serialCommandsEnabled = false;

    // Initialize MPU
    mpu.begin();

    // Read slaveID from EEPROM
    slaveIDs[0] = EEPROM.read(1);
    //Serial.print("SlaveID is ");
    //Serial.println(slaveIDs[0]);

    // Initialize slaveData
    for (uint32_t i = 0; i < 6; i++)
    {
      slaveData[i] = 0;
    }
    
    // Wait for the masters AP to appear and connect to it.
    //Serial.print("Waiting for Master AP to appear");
    WiFi.mode(WIFI_STA);
    WiFi.begin(APSSID, APPSK);
    while (WiFi.status() != WL_CONNECTED)
    {
      //Serial.print('.');
      delay(500);
    }
    WiFi.setAutoReconnect(true);
    masterIP = WiFi.gatewayIP();
    //Serial.print("\r\nConnected! Master IP: ");
    //Serial.print(masterIP);
    //Serial.print("  Slave IP: ");
    //Serial.println(WiFi.localIP());
    slaveConnectToMasterServerCallback();
    
    // Add slave tasks to scheduler
    scheduler.addTask(slaveReadMPU);
    slaveReadMPU.enable();
    scheduler.addTask(slaveSendData);
    slaveSendData.enable();
    scheduler.addTask(slaveConnectToMasterServer);
    slaveConnectToMasterServer.enable();
  }
  else
  {
    //Serial.println("Entering master setup");
    slave = false;
    
    WiFi.mode(WIFI_AP);
    WiFi.softAP(APSSID, APPSK);
    masterIP = WiFi.softAPIP();
    //Serial.print("Master AP up and running at ");
    //Serial.println(masterIP);

    // Start server
    //Serial.print("Starting Server... ");
    masterServer.begin();
    masterServer.setNoDelay(true);
    //Serial.println("Done!");
 }
}

void loop()
{
  scheduler.execute();

  if (serialCommandsEnabled)
  {
    if (Serial.available() >= 2)
    {
      uint8_t address = Serial.read();
      uint8_t data    = Serial.read();
      if (address == 1 && data)
      {
        EEPROM.write(address, data);
        EEPROM.commit();
        Serial.write(EEPROM.read(address));
      }
      else
      {
        Serial.write(0);
      }
    }
  }

  if (!slave)
  {
    // Master
    
    // Handle new clients if there are any.
    if (masterServer.hasClient())
    {
      serialCommandsEnabled = false;
      //Serial.println("There's something...");
      bool clientLimitReached = true;
      for (uint32_t i = 0; i < MAX_CLIENTS; i++)
      {
        if (!masterClients[i])
        {
          masterClients[i] = masterServer.available();
          masterClients[i].setNoDelay(true);

          // Wait for successful transmission of the slaveID
          uint32_t timeMS = millis();
          slaveIDs[i] = 0;
          while (!slaveIDs[i] && (millis() - timeMS) < 100)
          {
            if (masterClients[i].available())
            {
              slaveIDs[i] = masterClients[i].read();
            }
          }

          if (!slaveIDs[i])
          {
            // No slaveID received. Remove from list.
            masterClients[i].write(0);
            masterClients[i].flush();
            masterClients[i].stop();
            //Serial.println("Refused new client (invalid ID)");
          }
          else
          {
            masterClients[i].write(slaveIDs[i]);
            masterClientsTimeout[i] = millis() + DATA_PERIOD_MS * TIMEOUT_FACTOR;
            //Serial.print("New Client (id: ");
            //Serial.print(i);
            //Serial.println(")");
            clientLimitReached = false;
          }
          break;
        }
      }
      if (clientLimitReached)
      {
        WiFiClient noSpaceForYou = masterServer.available();
        noSpaceForYou.write(0);
        noSpaceForYou.flush();
        noSpaceForYou.stop();
        //Serial.println("Refused new client (no space)");
      }
    }

    // Check clients for new data
    for (uint32_t clientNum = 0; clientNum < MAX_CLIENTS; clientNum++)
    {
      uint32_t timeMS = millis();
      if (masterClients[clientNum].available() >= DATA_SIZE + 1)
      {
        uint8_t dataByte =  masterClients[clientNum].read();
        if (dataByte == slaveIDs[clientNum])
        {
          masterClientsTimeout[clientNum] = timeMS + DATA_PERIOD_MS * TIMEOUT_FACTOR;
          Serial.write(dataByte);
          for (uint32_t i = 0; i < DATA_SIZE; i++)
          {
            Serial.write(masterClients[clientNum].read());
          }
        }
      }
      else if (timeMS > masterClientsTimeout[clientNum])
      {
        masterClients[clientNum].flush();
        masterClients[clientNum].stop();
      }
      yield();
    }
  }
  else
  {
    // Slave
  }
}

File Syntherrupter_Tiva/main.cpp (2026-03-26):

/*
 * main.cpp
 *
 *  Created on: 26.03.2020
 *      Author: Max Zuidberg
 */


#include <stdint.h>
#include <stdbool.h>
#include <Sysex.h>
#include <System.h>
#include "InterrupterConfig.h"
#include "EEPROMSettings.h"
#include "Nextion.h"
#include "Coil.h"
#include "GUI.h"
#include "Files.h"
#include "MidiPlayer.h"


Nextion nextion;


void uartUsbISR()
{
    MIDI::usbUart.ISR();
}

void uartMidiISR()
{
    MIDI::midiUart.ISR();
}

void uartLightSaberISR()
{
    LightSaber::uart.ISR();
}

int main(void)
{
    System::init();

    uint32_t cfgStatus = EEPROMSettings::init();

    nextion.init(3, 115200);

    MIDI::init(115200, uartUsbISR, GPIO_PORTC_BASE, GPIO_PIN_4, GPIO_PIN_5, uartMidiISR);
    LightSaber::init(GPIO_PORTA_BASE, GPIO_PIN_6, GPIO_PIN_7, 115200, uartLightSaberISR);

    for (uint32_t coil = 0; coil < COIL_COUNT; coil++)
    {
        Coil::allCoils[coil].init(coil);
    }

    GUI::init(&nextion, cfgStatus);
    Sysex::init(&nextion);

    Files::init();
    Files::loadSorted();


    while (42)
    {
        GUI::update();

        Files::update();

        MIDI::process();
        Sysex::processSysex();
        LightSaber::process();

        switch (COIL_COUNT)
        {
            case 6:
                Coil::allCoils[5].updateData();
                Coil::allCoils[5].updateOutput();
            case 5:
                Coil::allCoils[4].updateData();
                Coil::allCoils[4].updateOutput();
            case 4:
                Coil::allCoils[3].updateData();
                Coil::allCoils[3].updateOutput();
            case 3:
                Coil::allCoils[2].updateData();
                Coil::allCoils[2].updateOutput();
            case 2:
                Coil::allCoils[1].updateData();
                Coil::allCoils[1].updateOutput();
            case 1:
                Coil::allCoils[0].updateData();
                Coil::allCoils[0].updateOutput();
                break;
        }
    }
}

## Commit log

2020-04-02 Dangerous glitch fixed
    https://e2e.ti.com/support/microcontrollers/other/f/908/p/893541/3303563
    [Output.h]
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2020-04-23 See Commit Details
    * Folder structure changed
    * Big step towards new GUI. NOT FINISHED! Tiva Source still untouched (a.k.a. not compatible)
    [GUI.cpp, MIDI.cpp, Nextion.h]
2020-04-24 Simple Mode and MIDI Live Mode working
    * New Command format. Way more effective than the old "pure Nextion command" communication. In normal operation the Microcontroller does not need to send any data at all.
    * Support for up to 6 Tesla Coils. In Simple and MIDI Live mode you can select which of them are affected by your next settings.
    * In MIDI Live mode: Assign channels to each tesla coil by holding its button. (A similar Settings page exists in Simple mode, too, but has nothing meaningful to say as of now).
    * Better sliders (touch without move is now working)
    * Skip Identification page if user2code is empty
    * probably forgot many things...
2020-04-25 It woerxxx!
    Independant control of up to 6 Tesla Coils
    Bug free Nextion - Tiva communication
    Nextion Firmware Updates over USB through the Tiva
    [GUI.cpp, MIDI.cpp, Nextion.h]
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2020-05-08 Removed backup code and fixed getExactSystemTimeUS
    [GUI.cpp]
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2020-05-14 Basically working, still issues.
    [GUI.cpp, MIDI.cpp, main.cpp]
2020-05-14 No UART ISR but FIFO, fixed channel association, now FaultISR...
    [GUI.cpp, MIDI.cpp]
2020-05-19 Cleaner Sound, Smaller fixes for MIDI and Nextion
    Nextion firmare is not backwards compatible!!
    [GUI.cpp, MIDI.cpp]
2020-05-20 Small fixes (see commit details)
    - Outputs didn't turn off when leaving simple mode
    - Coil 6 ontime always equal to coil 1 ontime
    - User 2 settings didn't change until reboot when coil limits were modified
    - Slight adjustments to the ADSR curves. Program 7 does no more turn off completely on long notes but stays at a low value.
    [GUI.cpp]
2020-05-21 Fixed FaultISR from last commit
    Better page exit handling. Instead of trying to do it with one case for simple, midiLive and settings mode, now each mode has its own exit command.
    Bonus: EE
    [GUI.cpp, MIDI.cpp]
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2020-06-14 Fixes for pitch bend and tuning
    [MIDI.cpp]
2020-07-03 Revert "View Firmware Versions on Startup"
    This reverts commit d162c594923c0f080244aef13e725c2cd35e60fe.
    [GUI.cpp]
2020-07-08 See Commit Details
    * Fixed MIDI UARTs (copy paste error)
    * Added Pan
    * Reduced optimization level from O4 to O3 to prevent strange string problems.
    * Probably forgot some stuff...
    [GUI.cpp, MIDI.cpp]
2020-07-09 Fixed Expression, Registered Parameters and Program Reset
    * Expression default was 0.0f. If a MIDI file did not send expression commands, this resulted in no audio at all.
    * Coarse and fine data entries of registered parameters were swapped.
    * MIDI program was reset by the controller reset command. This is no more the case (seems to be what SynthFont expects).
    [MIDI.cpp]
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2020-07-09 Fixed detuning of high notes
    [GUI.cpp, MIDI.cpp]
2020-07-09 ADSR Program Shift, Higher Effect Resolution, Fixes
    * ADSR program 0 disables ADSR. All other ADSR programs are shifted by 1.
    * Increased note period tolerance from 1/16th to 1/2. Seems to sound better with many voices (especially with 6 coils).
    * Fixed MIDI program out of range in some cases
    * Increased system time resolution to 500us (previously: 1ms). Doesnt seem to change a lot though.
    [GUI.cpp, MIDI.cpp, main.cpp]
2020-07-09 Reduced System Time Resolution back to 1ms
    ... and fixed EE for the new ADSR program numbers
    [main.cpp]
2020-07-12 Moved Controller Reset to Channel Class
    [MIDI.cpp]
2020-07-12 No-ADSR Note Stop fixed
    [MIDI.cpp]
2020-07-12 Eliminated unecessary re-calculations and duty limit fix (see details)
    Duty Limiter:
    The duty limiter was applied to all notes for each active note, causing excessive ontime reduction. Fixed.
    Unecessary re-calculations
    If only one single parameter changed, *all* notes of all outputs were recalculated (frequency including pitch bend, rawOntime, ...). Of course, with up to 48 active notes this means up to 47 unnecessary, time consuming calculations.
    From now on only the notes that are actually modified by a MIDI command will be recalculated. Only exception is a controller change. This causes a recalculations of all notes of a coil which listens to this channel, even if those notes belong to a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
    [MIDI.cpp]
2020-07-13 Coil specific voice limit and 16 voices max
    Thanks to the optimizations of the last commit, 16 voices per coil are now possible. Since this is too much in many cases, the user can limit the number voices for each coil to any value.
    [GUI.cpp, MIDI.cpp]
2020-07-16 NRPs! See Commit Details
    * Map note frequencies to pan positions via NRPs (documented somewhere else. Soon.)
    * Added "Omni Mode" (NRP) which says that notes from this channel are "everywhere" on the pan range and thus play on all coils at a 100% - no matter where these coils are placed.
    * Since it seemed more usefule to not reset NRPs when a channel reset command is received, the GUI now features a "NRP Reset" butten which does exactly what it says. For all channels. This - yet again - caused a non-compatible change to the Nextion-Tiva communication protocol.
    * When adding the NRP features I fixed a bug which messed up (N)RP adresses and data if more than one channel sends (N)RPs at the same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
    [GUI.cpp, MIDI.cpp]
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2020-07-18 Fixed Nextion FW Upload for new Editor
    Because there is a new dialog between the port scan and the actual upload, the simple timeout = end of update method didn't work anymore. Now a minimum upload time of 15 seconds is required which seems to work.
    [GUI.cpp]
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2020-07-24 Replaced powf by exp2f
    Don't know if it helps but if there is a specialized function for a certain use case I expect it to be at least as good/fast as the generalized function.
    [MIDI.cpp]
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2020-07-24 Added constant mode and fixed reach=0
    When pan is enabled, volume normally drops with the distance to the coil. This can be disabled. In that case the coil plays all notes within reach at their nominal volume.
    [MIDI.cpp]
2020-07-24 Nextion: Added constant mode and fixed reach=0
    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
2020-07-24 Fixed "blind spot"
    There was one case where a note could sit exactly in the middle between two coils and the pan reach would not cover it although you'd expect it. Simple rounding error.
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2020-07-24 Definitely ready for beta 5
    Next button on MIDI Coil Settings page didn't work correctly if the number of outputs was lower than 6. It didn't disappear and and allowed to modify "non existing" coils.
2020-07-25 Fixed Zero Ontime in MIDI Live Mode
    It would actually become a 1us ontime.
    [MIDI.cpp]
2020-07-29 See Commit Details (MIDI Chn Editor, etc)
    * Set NRPs or send any MIDI command you want. Access this page by holding a channel number.
    * Buttons that have "hidden" functions which can be accessed by holding the button have now a different icon.
    * Missed something in the last commit message: Replaced sqrt algorithm. The previous one suffered from overflow issues.
    [GUI.cpp, MIDI.cpp]
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2020-08-10 UART Pin List/Direct MIDI In finally fixed and tested!
    Yet another stupid copy paste error in the UART pin list...
    [MIDI.cpp, Nextion.h]
2020-08-15 "Recovery mode" to allow Nextion Firmware Updates if FW doesnt work
    If the TIva microcontroller can't connect to the Nextion display within 3 seconds after startup, it assumes there's something wrong and enters Nextion firmware update mode to allow to change the (corrupted) firmware.
    Until now you needed a working Nextion firmware to be able to enter the Nextion FW update mode.
    [GUI.cpp]
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2020-08-25 processBuffer fixed and optimized, assignedTone Array, ADSR fixed
    [MIDI.cpp]
2020-08-25 ADSR fixed + time per note, MIDI::process fault tolerant.
    [MIDI.cpp]
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2020-09-01 More inlining, more audio quality, emergency stop completed, and tons of other stuff
    * Correct calling of static member functions
    * Removed remaining sys objects (System is static now)
    * Doubly linked notelist (same idea as tonelist)
    * Tones can remove themselves from the tonelist they belong to
    * MIDI UART Buffers increased back to 1024 bytes. Probably not necessary but who cares - with 256kB of SRAM...
    * Enable/Disable UARTs
    [GUI.cpp, MIDI.cpp]
2020-09-03 Fixed minimum offtime rounding error
    "Unlucky" sys time increments could cause too short min offtimes. Now they are guaranteed to be at least the specified value and at most one sys time increment longer.
    [GUI.cpp]
2020-09-07 Various Fixes and Enhancements for Lightsaber Mode (See Commit Details)
    * Working packet detecten (has to be tested with multiple lightsabers though)
    * Ignore all zero data
    * 4 lightsabers max
    * Init GUI as last class. This makes sure that the user can't do anything until everything is up and running.
    * Basic algorithm for tone generation. Not good yet.
    * Set ESP ID
    * Fixes, fixes, fixes
    [GUI.cpp, main.cpp]
2020-09-08 Faster Sampling, Peak Transmission, MPU6050 Reset on Startup
    [Syntherrupter_Lightsaber.ino]
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2020-09-16 (Untested) ADSR loops and Fix for ADSR release in some cases
    [MIDI.cpp]
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2020-09-25 MIDI Buffer Fixed - ADSR (Release) Fixed
    The new buffer stuff from one of the last commits was untested. Now I know it works. (didn't test multiple buffers at once though).
    ADSR Release Step calculations fixed. and the other steps too btw. now it is possible to have "sustain" go down to 0 (which was impossible before). Release is always calculated on the last non 0 step.
    [MIDI.cpp]
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2020-10-14 Hotfix for Dark Mode
    fLoadColors needs to be the last component of every page, otherwise dark mode won’t work (for components following fLoadColors). Forgot this when working on the Help page...
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2020-11-15 Fixed channels[].controllersChanged
    Previous way of setting the variable involved explicit setting to false which could lead to some changes not be applied if multiple MIDI commands are processed in a row.
    [MIDI.cpp]
2020-12-03 Updated/Fixed Nextion2Text, Modified Colors, ... (See commit details)
    * Many initial values were wrong previously because of bugs in the Nextion2Text script. Additionally it now supports more properties.
    * Another bug was that timer events were not parsed at all.
    * QR code would not stay visible under all circumstances. Fixed.
    * The apply mode buttons have been replaced by a single button, which is the cleaner overall solution.
    * Page Help & Info: QR code for the credits link
    * Changed Dark Mode colors for better readability
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2021-01-10 Pitchbend + Sustain Pedal Fix
    If a note was hold by the sustain pedal, pitchbend wouldn't affect it.
    [MIDI.cpp]
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2021-03-18 Fixed: (Channel) Note list issues
    The channel lists and the main notelist were not always in sync. Some notes didn't get removed from the channel list. Handling of both lists was not good. Now notes are always removed properly from both lists.
    Also, notes now contain a direct pointer to the channel object they belong to instead of the channel number.
    [MIDI.cpp]
2021-03-18 Fixed: MIDI Program out of range
    stupid.
    [MIDI.cpp]
2021-03-31 Replaced pointers by references
    Makes it easier to read IMO, especially since this eliminates pointers to pointers.
    [MIDI.cpp]
2021-04-01 Fixed MIDI Running Status.
    Had been broken by the iterative processing introduced somewhere within the v4.0.0 rework.
    [MIDI.cpp]
2021-04-03 Undo wrong CC modification
    [MIDI.cpp]
2021-04-05 Shortened variable name to solve issue #11
    Turns out the Nextion screen - unlike the editor - thinks this name is too long. But only over serial! Thank you very much.
    [GUI.cpp]
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2021-05-27 New EEPROMSettings (See Commit Details)
    New EEPROMSettings:
    * Using union many things get a lot easier
    * Strictly checks and writes on a page base, thus acting in the most efficient way possible
    * Structures for migration from older settings version to newer one (no actual migration yet). So far the settings were lost with every new settings version
    * All other classes directly point to the EEPROM data (in RAM) thus no manual sync between EEPROMSettings and other clases needed. Writing/Updating of the actual EEPROM still needs to be triggered though.
    * All in all not tested yet, and not completed either.
    Other changes:
    * Fixed: Sysex User PW command would reset the username instea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
    [GUI.cpp, MIDI.cpp]
2021-05-29 Some progress, some bugfixes, some renames, not done yet.
    * Import from previous EEPROM layout version
    * Better warning when import/loading fails
    * Settings.x renamed to Sysex.x
    * All (EEPROM) data is stored in EEPROMSettings; other classes only point to this data (still issues).
    * Sysex user name/pwd fixed (had memcpy source/target wrong)
    * ByteBuffer renamed to Buffer and templated
    * Proper initialization of a default configuration if no valid config was found in EEPROM
    * Finally removes the ADSR_LEGACY_PROGRAMS array from the MIDI class
    [GUI.cpp]
2021-05-29 Testing and Fixing new EEPROM Stuff...
    * Fixed object inits (to correctly apply the values read from EEPROM)
    * Removed references to pointers. Doesn't work
    * Fixed pointer array pointer addressing indexing stuff. Confusing.
    * MIDI::lfoPeriodUS now part of the EEPROM (Sysex command not existing yet)
    [GUI.cpp, MIDI.cpp]
2021-05-29 Sysex and EEPROM enhancements and fixes
    Sysex:
    * Fixed: float commands were ignored
    * Fixed: Incorrect parameter number decoding. Specified this behavior in the documentation
    * Fixed: minor wrong/missing specs in the sysex documentation.
    * Fixed: various wildcard commands would only work for the first target (because the value broke after the first iteration).
    * Implemented: Simple mode ontime and BPS filter factors/constants
    * Implemented: EEPROM Update Mode and storing of Sysex commands in general
    * Implemented: All user commands incl. transmission to display
    * Implemented: Coil min ontime
    * Added: Device ID command
    * Added: [NS] Coil Output Invert
    EEPROM:
    * (New) Wri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
    [GUI.cpp, MIDI.cpp]
2021-05-30 Hardcoded Device ID fixed (now points to EEPROMSettings)
    [MIDI.cpp]
2021-06-10 Buffer swap glitch free!
    [Output.h]
2021-06-10 Buffering sort of works but many issues to do
    * Works okay-ish for 1 output with no others active.
    __* Single tone is pretty much perfect
    __* Multi-tone gets rather bad quickly. No clue why
    __* Envelopes don't work??
    * Multiple outputs cause glitches. Noooo idea why.
    [Output.h, main.cpp]
2021-06-17 Buffering, Take 2: Single FIFO, looking good
    For some reason the ping pong buffer sounded like crap and didn't work with multiple outputs. Therefore I tried with a single FIFO buffer among a lot of other changes. The single buffer makes a lot of things easier and so far sounds great - most of the time. There're still issues.
    [Output.h]
2021-06-18 LFO Fix (2)
    The EEPROM Migration from v2 to v3 goofed up the LFO value. It'll be fixed with the migration code from v3 to v4
    [MIDI.cpp]
2021-06-18 EEPROM Settings v4
    Added/fixed LFO parameters
    Added buffer time
    [MIDI.cpp]
2021-08-15 Fix: Removed factor 1000 from duty
    [GUI.cpp, MIDI.cpp]
2021-08-15 Moved channel volume and expression from raw to finishedVolume
    There was a reason I can't remember... That reason aside it should be faster since it doesn't require the controllersChanged flag anymore.
    [MIDI.cpp]
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2021-08-15 WIP: Buffer Unification (and other minor WIP things)
    Unification
    Since the output timer interrupts form the timebase for the entire output signal generation stuff, looong periods essentially stop the output generation. This means the periods can't be too long. At the same time the buffer already have a defragmentation to prevent the periods from getting arbitrarily small.
    This new thing is therefore called unification. The defragmentation remains in place but as an additional step, any (resulting) period higher than a given threshold is split into smaller ones below the threshold. This guarantees a minimum resolution in the signal generation.
    Code isn't final yet (hence WIP) but it has been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
    [Output.h]
2021-08-15 Fixed: ontime glitch for the first couple ontimes of certain notes
    Especially noticeable with certain very low volume notes. They "pop" at the beginning.
    Origin: finishedVolume isn't initialized when a new note is added since it's "always" controlled by updateEffects. However, updateEffects only does something when the note's been around for at least as long as the effect resolution. So before the first actual effect update the finishedVolume is undefined .
    One could rewrite updateEffects to handle this differently. Or one simply initializes finishedVolume to 0 for a new note. Problem solved.
    [MIDI.cpp]
2021-08-16 Fixed: MIDI Voice Limit
    There were lots of cases where the previous concept didn't work. Basically, it previously limited how many _modified_ notes would get through. Existing, unmodified notes were not counted.
    Now it counts correctly and adds or removes the notes as one would expect.
    Additionally it previously kinda kept the oldest notes, ditching newer ones while it should be (and now is) vice versa.
    [MIDI.cpp]
2021-08-17 Fixed: iteration over changing notelist caused FaultISR
    Using list members as endpoint for loops that change that list was maybe not the best idea...
    [MIDI.cpp]
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2021-08-23 Fixed: Some note don't play with omni mode
    If the note happened to have the same pan position as the previous note (occupying the same place in the notelist), the pan stuff wouldn't update and correct the pan volume to 1.0f as the omni mode should do.
    The fix makes sure every new note gets a pan update
    [MIDI.cpp]
2021-08-23 Fix: repetitive notes (with pedal) not always audible
    If the voice limit's exceeded only the newest X notes play. However, when a note is hit again (meaning it's not an all new note but a "refresh" of an existing one) it wouldn't move to the top of the list and thus not be part of the X notes that are actually audible.
    [MIDI.cpp]
2021-08-23 Fix: Pedal lifts could be missed
    Pedal lifts are sometimes very short. Since Syntherrupter (pre)processes all incoming MIDI data before actually updating any notes, it may process both the pedal lift and press before updating the notes. Hence that second update doesn't know the pedal got lifted and the notes are not released.
    The fix makes sure even short pedal lifts are always applied.
    [MIDI.cpp]
2021-09-13 Fixed: Tiva doesn't enter nxt passthrough automatically...
    ... when it fails to connect to the Nextion on startup.
    [main.cpp]
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2021-09-20 Support for "headless" operation and passthrough-mode fix
    Syntherrupter would only enter passthrough mode if *no* Nextion screen at all is connected. Which doesn't make too much sense. On the other hand, Syntherrupter would *not* enter passthrough mode if a screen is connected but has no or the wrong firmware.
    Now, when no screen is connected, syntherrupter can be controlled via sysex. And if a screen is connected, it works as one would expect.
    [GUI.cpp]
2021-09-28 Unified mode start/stop
    Replaced different start/stop/getRunning/isPlaying/... methods by unified get/setRunning. Much easier to deal with.
    [MIDI.cpp]
2021-09-28 UART::write and other things
    * Buffer:
    * Buffer size is now determined at compile time.
    * Added Buffer::avail
    * Fixed: Buffer::level() would return zero instead of size for a full buffer
    * Minor branchless optimizations
    * UART
    * Added TX buffer
    * renamed RX buffer
    * Modified ISR for writing
    * Removed unbuffered option for init.
    * Unified all buffer sizes to 512
    * Some general housekeeping
    [MIDI.cpp, UART.h]
2021-09-28 More sysex read support and various small improvements
    * Sysex: read support for most commands, except
    * User name/password
    * Coil Limits
    * Envelopes
    * Sysex: fixed: various UI settings not stored in EEPROM
    * UI Display Brightness
    * UI Button Hold Time
    * UI Sleep Delay
    * UI Color Mode
    * MIDI: (more) consistent 0.0f-1.0f ranges for public methods.
    * MIDI: Consistent 127 ranges (instead of 128)
    * Nextion: added method to check if screen is present (previously that info was only available as return value of the init)
    * Various get*** methods
    [GUI.cpp, MIDI.cpp, Nextion.h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]
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2021-10-04 Fixed: Race condition causes corrupted notelist (hanging tones)
    On the second byte of an note on command the associated note object is retrieved - if there is any. However, because of the per-byte processing of MIDI commands, the function returns. If the next byte is not yet available, other things are processed. If on top of that the specific note retrieved above ends right now it gets removed from the notelist.
    Now, on the third byte of the note on command, the note is marked and treated as existing even though it's not, causing the notelist to become corrupted. Hanging tones are the result in this case.
    The fix is simple: make the Note On Event handling atomic. Do both retrieving and modi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
    [MIDI.cpp]
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2021-10-19 Improved connection handling (now works with reparse mode)
    Admitted, this fixes a rather theoretical bug.
    [Nextion.h]
2022-08-07 MIDI Tuning RPN fixed
    Fine Tuning was mapped to -2..2 instead of -1..1 semitones
    Coarse Tuning was "mapped" to 0..127 instead of -64..63 semitones
    [MIDI.cpp]
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2022-09-17 Renamed missed Note::envelopeTimeUS to Note::effectTimeUS
    [MIDI.cpp]
2022-09-17 Fixed: Nextion Coil Limits require restart
    Only the EEPROM values are updated immediately. The functions to apply the values to the right places were not called.
    Bug present since v4.2.0-beta.3
    [GUI.cpp]
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2024-06-09 More Bugfixes and Improvemets
    Added: Startup: Power cycling suggestion on timeout.
    Improved: Settings: Discard also discards on-screen changes.
    Improved: Other_Settings: Less global RAM usage (global components => global variables).
    Fixed: Darkmode/Lightmode change not saved (bug since 4.3.0-beta.1).
    Fixed: Changing most settings from A->B->A results in value B (instead of A).
    Fixed: General Settings not being saved properly.
    [GUI.cpp]
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2024-12-22 Fixed: RX/TX Wiring and Colors
    [Syntherrupter Complete Fritzing.fzz]
2026-02-22 Improved: Simplified ToneList (...) (untested)
    The linked list concept added more complexity and likely hurt performance at the same time. Mode classes now get a fixed index range and they access
    Improved: finished support for random frequency tones. Only uniformely distributed frequencies between a min and max are possible for now. Duty cycle limiter uses the (expected) (long)time averaged duty.
    Improved: duty cycle limiter respects minOntime now and drops it if the duty limit was exceeded otherwise. It is not yet the smartest algorithm but for now it's a good compromise between complexity and effectiveness.
    Two main limitations:
    1. Either all tones get the minOntime added, or none. There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
    [MIDI.cpp]
2026-02-23 Various ToneList Fixes
    - Duty calculation issues (divide by zero period)
    - Stopped notes are not removed from all coils
    - Simple Mode not adjusting lastUpdateUS
    - Inactive tones generate minOntime ontimes anyway
    [MIDI.cpp]
2026-02-25 Fixed: MIDI CC All Sounds Off not working
    [MIDI.cpp]
2026-02-26 Fixed: EE Celebration
    Sysex command was not implemented. Also: updated MIDI Program
    [GUI.cpp]
